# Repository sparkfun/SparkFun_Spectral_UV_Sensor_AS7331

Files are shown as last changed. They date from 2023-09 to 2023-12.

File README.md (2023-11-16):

SparkFun Spectral UV Sensor - AS7331 (Qwiic) 
========================================

<table class="table table-hover table-striped table-bordered">
    <tr align="center">
        <td><a href="https://www.sparkfun.com/products/23517">Standard</a></td>
        <td><a href="https://www.sparkfun.com/products/23518">Mini</a></td>
    </tr>
    <tr align="center">
        <td><a href="https://www.sparkfun.com/products/23517">SparkFun Spectral UV Sensor - AS7331 (Qwiic)</a></td>
        <td><a href="https://www.sparkfun.com/products/23518">SparkFun Mini Spectral UV Sensor - AS7331 (Qwiic)</a></td>
    </tr>
</table>

The SparkFun Spectral UV Sensor - AS7331 (Qwiic) features the AS7331 UV sensor from ams OSRAM<sup>&copy;</sup> and measures UV radiation on three channels: UVA (320-400nm), UVB (280-320nm), and UVC (200-280nm) with high sensitivity and accuracy. The three channels on the AS7331 each have individual photodiodes with built-in interference filters. The sensor has three operating modes: Single Measurement (CMD), Continuous Measurement (CONT), and Synchronized Measurement (SYNx) with an automatic power down sequence between measurements for low current consumption in all three modes. 

Repository Contents
-------------------

* **/Documentation** - Data sheets, additional product information
* **/Hardware** - Eagle design files (.brd, .sch)
* **/Production** - Production panel files (.brd)
* **/docs** -  Documentation files for the Spectral UV Sensor
* **/overrides** -  Overrides for GitHub pages content

Documentation
--------------
* **[Library](https://github.com/sparkfun/SparkFun_AS7331_Arduino_Library)** - Arduino library for the Spectral UV Sensor - AS7331 (Qwiic).
* **[Hookup Guide](https://sparkfun.github.io/SparkFun_Spectral_UV_Sensor_AS7331)** - Basic hookup guide for the Spectral UV Sensor - AS7331 (Qwiic).

Product Versions
----------------
* [SEN-23517](https://www.sparkfun.com/products/23517) - Spectral UV Sensor - AS7331 (Qwiic)
* [SEN-23518](https://www.sparkfun.com/products/23518) - Mini Spectral UV Sensor - AS7331 (Qwiic)

License Information
-------------------

This product is _**open source**_! 

Please review the LICENSE.md file for license information. 

If you have any questions or concerns on licensing, please contact technical support on our [SparkFun forums](https://forum.sparkfun.com/viewforum.php?f=152).

Distributed as-is; no warranty is given.

- Your friends at SparkFun.

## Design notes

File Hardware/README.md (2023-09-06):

SparkFun <PRODUCT NAME> Design Files
=====================================

The .sch and .brd files hare are Eagle CAD schematic and PCB design files from SparkFun Electronics.
A freeware version of Autodesk Eagle can be found [here](https://www.autodesk.com/products/eagle/free-download).

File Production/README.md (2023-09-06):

SparkFun <PRODUCT NAME> Production Files
=========================================

These are the production files SparkFun uses for printing PCBs.

License Information
-------------------
This product is open source! 

The hardware is released under [Creative Commons ShareAlike 4.0 International](https://creativecommons.org/licenses/by-sa/4.0/).

Please use, reuse, and modify these files as you see fit. Please maintain attribution to SparkFun Electronics and release anything derivative under the same license.

Distributed as-is; no warranty is given.

- Your friends at SparkFun.

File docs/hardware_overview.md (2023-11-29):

---
icon: material/cog
---

## AS7331 Spectral UV Sensor

The AS7331 spectral UV sensor from ams measures UV radiation over three channels (UVA, UVB, and UVC). Each channel is isolated from the other and has its own photodiode with a built-in filter to help with accuracy and interference from other channels.

<div class="grid" markdown>

<div markdown>
<figure markdown>
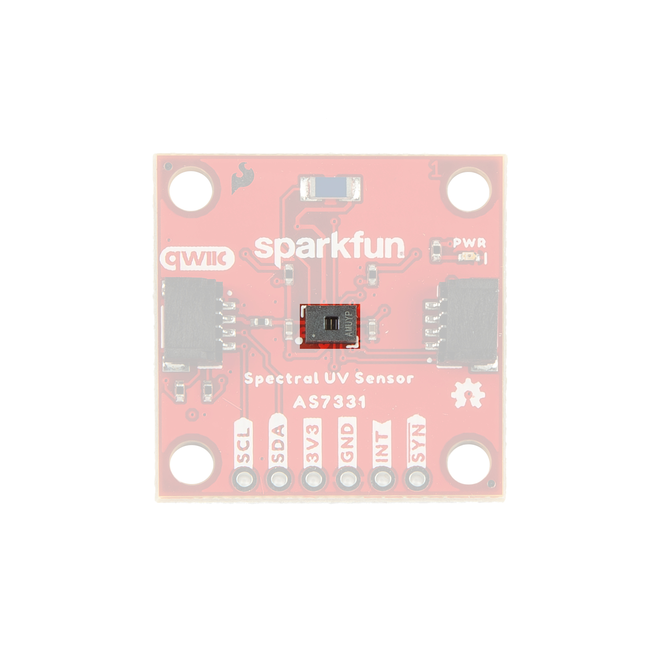
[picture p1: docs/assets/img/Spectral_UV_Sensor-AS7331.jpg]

</figure>
</div>

<div markdown>
<figure markdown>
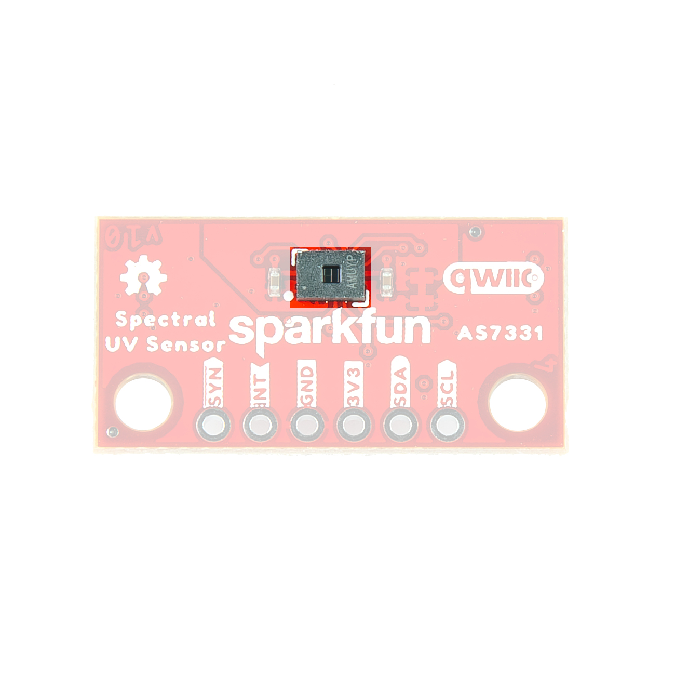
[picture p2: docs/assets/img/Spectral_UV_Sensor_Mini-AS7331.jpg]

</figure>
</div>

</div>

The AS7331 has extensive configuration options to customize the sensor's responsiveness, sensitivity, clock speed, and conversion time, among other settings. These configuration options allow users to optimize the sensor for their application. For example, a high gain setting results in a more sensitive response from the sensor but a lower maximum detectable irradiance (in &micro;W/cm<sup>2</sup>) whereas a low gain has much less sensitivity but a much higher maximum detectable irradiance. For detailed information on the conversion equations and how all the available settings affect performance, refer to section 7.4 of the [datasheet](./assets/component_documentation/AS7331_DS001047_4-00.pdf) Note, these configurations apply across all three channels. It has four operating modes: Command (CMD), Continuous (CONT), Synchronized Start (SYNS), and Synchronized Start/End (SYND). The list below outlines the operating modes' behaviors: 

* CMD Mode - "One-shot" mode. Takes a single measurement and conversion controlled by the I<sup>2</sup>C interface.
* CONT Mode - Continous mode. Takes continuous measurements and conversions on set intervals. 
* SYNS Mode - Synchronized start mode. A connected microcontroller starts measurements through an I/O pin connected to the SYN pin.
* SYND Mode - Synchronized start and stop mode. A connected microcontroller starts and stops measurements through an I/O pin connected to the SYN pin.

 The sensor operates over I<sup>2</sup>C with a pin-configured I<sup>2</sup>C address supporting four separate addresses (the breakout board sets this to 0x74 by default). Refer to the [datasheet](./assets/component_documentation/AS7331_DS001047_4-00.pdf) for a complete overview of the AS7331.

## Qwiic and PTH Pins

Both boards include a pair of Qwiic connectors for the I<sup>2</sup>C interface (SDA, SCL, 3.3V, and Ground) as well as a 0.1"-spaced plated through hole (PTH) header that includes power supply pins (3.3V and Ground) the I<sup>2</sup>C interface as well as the AS7331's SYNC and READY/INT pins.

<div class="grid" markdown>

<div markdown>
<figure markdown>
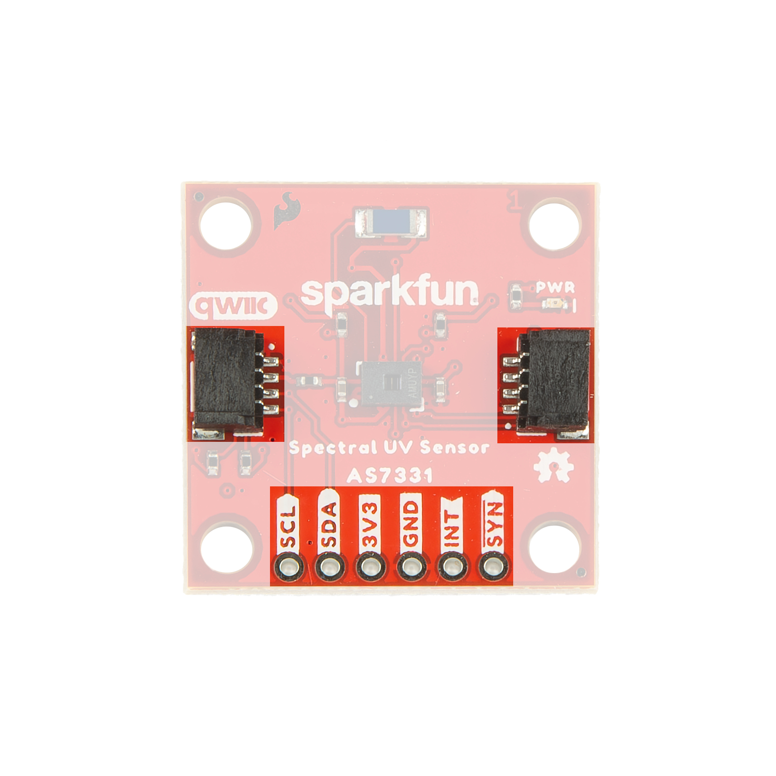
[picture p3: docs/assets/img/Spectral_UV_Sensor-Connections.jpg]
Highlighting the Qwiic connectors & PTH pins on the standard board

</figure>
</div>

<div markdown>
<figure markdown>
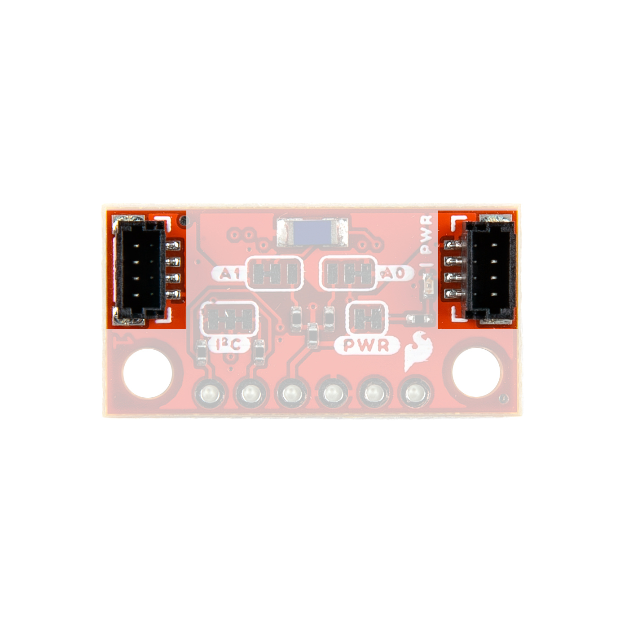
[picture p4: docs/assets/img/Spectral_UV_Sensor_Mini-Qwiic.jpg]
Highlighting the Qwiic connectors on the standard board

</figure>
</div>

</div>

### Power

The AS7331 accepts a supply voltage between <b>2.7V</b> and <b>3.6V</b>. Power to these boards can be supplied either over one of the Qwiic connectors or through the <b>3.3V</b> and <b>GND</b> PTH pins.

## LEDs

These breakouts only have a red Power LED to indicate whenever the board is powered.

<div class="grid" markdown>

<div markdown>
<figure markdown>
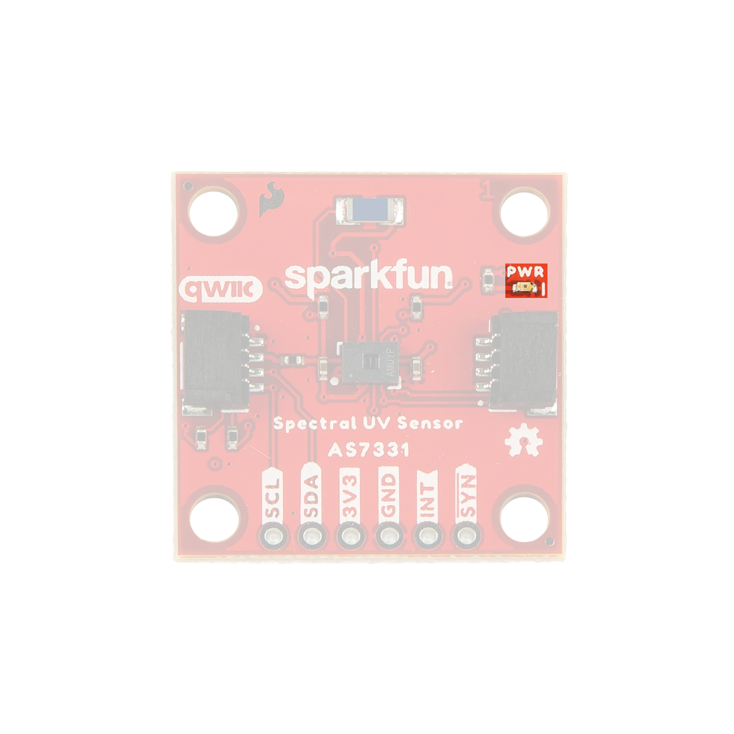
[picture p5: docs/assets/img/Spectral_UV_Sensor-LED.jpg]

</figure>
</div>

<div markdown>
<figure markdown>
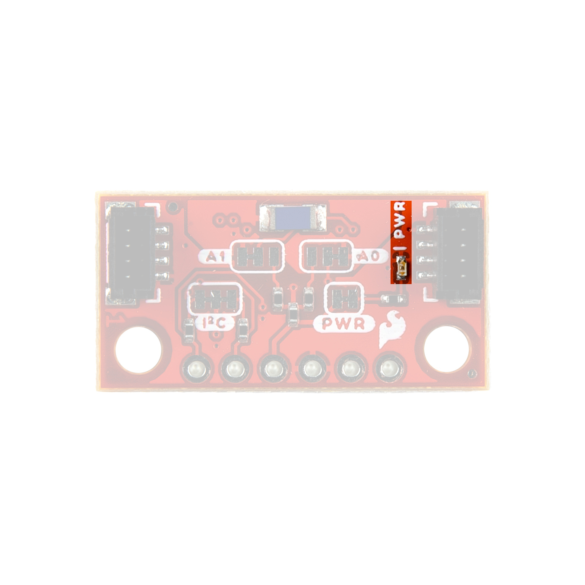
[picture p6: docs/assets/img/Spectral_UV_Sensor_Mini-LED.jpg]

</figure>
</div>

</div>

## Jumpers

??? note "Never modified a jumper before?"
	Check out our <a href="https://learn.sparkfun.com/tutorials/664">Jumper Pads and PCB Traces tutorial</a> for a quick introduction!
	<p align="center">
		<a href="https://learn.sparkfun.com/tutorials/664">
		Tutorial's thumbnail<br>
        How to Work with Jumper Pads and PCB Traces</a>
	</p>

The boards have three solder jumpers labeled <b>PWR</b>, <b>A0</b>, and <b>A1</b>. The PWR jumper completes the power LED circuit. Open it to disable the Power LED to help reduce the current consumption. The A0 and A1 solder jumpers control the AS7331's I<sup>2</sup>C address. They default to tie both address pins to Ground to set the I<sup>2</sup>C address to <b>0x74</b>. The table below outlines the jumper positions for the four available I<sup>2</sup>C addresses:

<div class="grid" markdown>

<div markdown>
<figure markdown>
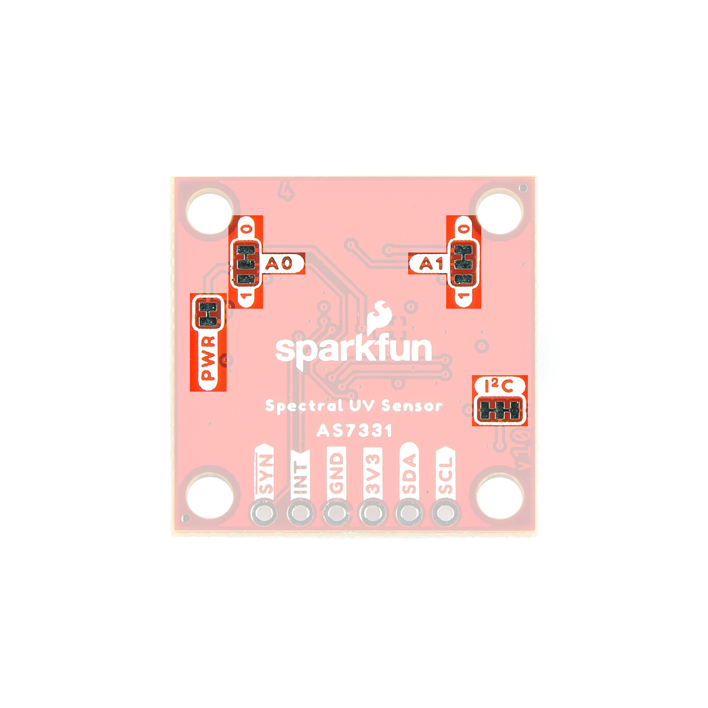
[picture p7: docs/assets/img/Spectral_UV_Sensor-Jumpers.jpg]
Highlighting the solder jumpers on the standard board

</figure>
</div>

<div markdown>
<figure markdown>
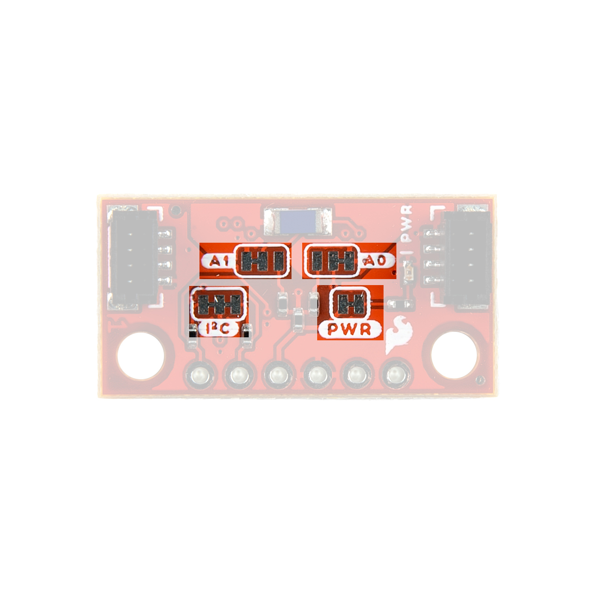
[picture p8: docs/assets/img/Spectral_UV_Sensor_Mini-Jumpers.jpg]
Highlighting the solder jumpers on the standard board

</figure>
</div>

</div>

<center>
<table>
	<tr>
		<th>A1</th>
		<th>A0</th>
		<th>Address</th>
	</tr>
	<tr>
		<td>GND</td>
		<td>GND</td>
		<td>0x74 (default)</td>
	</tr>
	<tr>
		<td>GND</td>
		<td>VDD</td>
		<td>0x75</td>
	</tr>
	<tr>
		<td>VDD</td>
		<td>GND</td>
		<td>0x76</td>
	</tr>
	<tr>
		<td>VDD</td>
		<td>VDD</td>
		<td>0x77</td>
	</tr>
</table>
</center>
## Board Dimensions

The Standard version of the Spectral UV Sensor measures 1.00" x 1.00" (25.4mm x 25.4mm) and the Mini version measures 1.00" x 0.50" (25.4mm x 12.7mm). The Standard has four mounting holes and the Mini has two mounting holes. All of these fit a [4-40 screw]().

<div class="grid" markdown>

<div markdown>
<figure markdown>
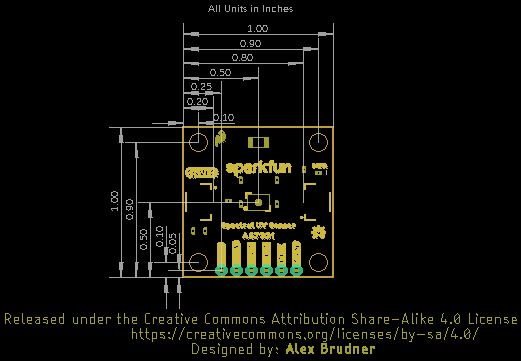
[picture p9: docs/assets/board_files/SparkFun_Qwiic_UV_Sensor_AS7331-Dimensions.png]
Spectral UV Sensor Standard Board Dimensions

</figure>
</div>

<div markdown>
<figure markdown>
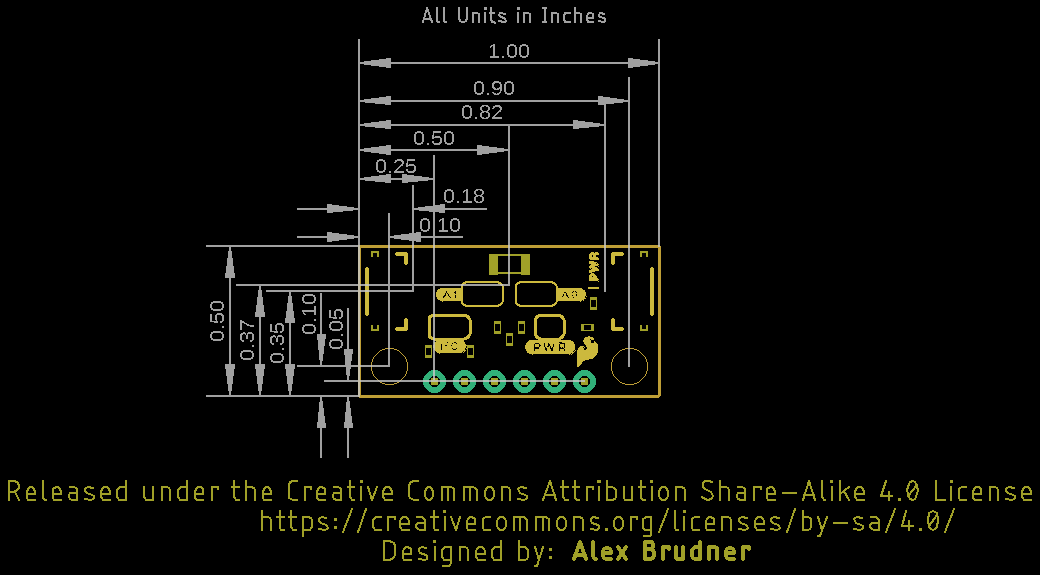
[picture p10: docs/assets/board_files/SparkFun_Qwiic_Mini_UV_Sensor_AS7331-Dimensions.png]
Spectral UV Sensor Mini Board Dimensions

</figure>
</div>

</div>

??? tip "Need more measurements?"
	For more information about the board's dimensions, users can download the Eagle files([Standard](./assets/board_files/SparkFun_Qwiic_UV_Sensor_AS7331.zip) & [Mini](./assets/board_files/SparkFun_Qwiic_Mini_UV_Sensor_AS7331.zip)) for the board. These files can be opened in Eagle and additional measurements can be made with the dimensions tool.

	??? info ":octicons-download-16:{ .heart } Eagle - Free Download!"
		Eagle is a [CAD]("computer-aided design") program for electronics that is free to use for hobbyists and students. However, it does require an account registration to utilize the software.

		<center>
		[Download from<br>:autodesk-primary:{ .autodesk }](https://www.autodesk.com/products/eagle/free-download "Go to downloads page"){ .md-button .md-button--primary width="250px" }
		</center>
	
	??? info ":straight_ruler: Dimensions Tool"
		This video from Autodesk demonstrates how to utilize the dimensions tool in Eagle, to include additional measurements:

		<center>
		<div class="video">
		<iframe src="https://www.youtube.com/embed/dZLNd1FtNB8" title="EAGLE Dimension Tool" frameborder="0" allow="accelerometer; autoplay; clipboard-write; encrypted-media; gyroscope; picture-in-picture" allowfullscreen></iframe>
		</div>
		</center>

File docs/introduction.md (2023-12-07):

---
icon: material/book-open-page-variant
---

The SparkFun Spectral UV Sensor - AS7331 (Qwiic) and Mini Spectral UV Sensor - AS7331 (Qwiic) feature the AS7331 UV sensor from ams OSRAM<sup>&copy;</sup> which measures UV radiation on three channels: UVA (320-400nm), UVB (280-320nm), and UVC (200-280nm). Each channel on the AS7331 has an individual photodiode with built-in interference filters to ensure high sensitivity and accuracy across all three channels. The AS7331 communicates over I<sup>2</sup>C so naturally we put it on Standard (1"x1") and Mini (1"x0.5") Qwiic breakouts to integrate into our [Qwiic Connect System](https://www.sparkfun.com/qwiic).

<section class="grid cards col-2"markdown>

-	<a href="https://www.sparkfun.com/products/23517">
	**SparkFun Spectral UV Sensor - AS7331 (Qwiic)**<br>
	**SKU:** SEN-23517

	---

	<figure markdown>
	https://cdn.sparkfun.com/r/600-600/assets/parts/2/3/8/0/8/23517-Spectral-UV-Sensor_Feature.jpg
	</figure>
	</a>

	<center>
    [Purchase from SparkFun :fontawesome-solid-cart-plus:{ .heart }](https://www.sparkfun.com/products/23517){ .md-button .md-button--primary }
    </center>

-	<a href="https://www.sparkfun.com/products/23518">
	**SparkFun Mini Spectral UV Sensor - AS7331 (Qwiic)**<br>
	**SKU:** SEN-23518

	---

	<figure markdown>
	https://cdn.sparkfun.com/r/600-600/assets/parts/2/3/8/0/9/23518-Spectral-UV-Sensor-Mini_Feature.jpg
	</figure></a>

	<center>
	[Purchase from SparkFun :fontawesome-solid-cart-plus:{ .heart }](https://www.sparkfun.com/products/23518){ .md-button .md-button--primary }
	</center>

</section>

This guide goes over the AS7331 UV sensor and other hardware on these Qwiic breakouts, how to assemble them into a circuit and how to use them with the SparkFun AS7331 Arduino library.

## Required Materials

In order to follow along with this guide, you'll need the following materials. You'll need a microcontroller to connect the breakouts to. The development boards listed below come with Qwiic connectors for easy connection using the Qwiic system:

<div class="grid cards" markdown>

-   <a href="https://www.sparkfun.com/products/19177">

    <figure markdown>
    SparkFun IoT RedBoard - ESP32 Development Board
    </figure>
    </a>
    ---
    <a href="https://www.sparkfun.com/products/19177">
    **SparkFun IoT RedBoard - ESP32 Development Board**<br>
    DEV-20168
    </a>

-   <a href="https://www.sparkfun.com/products/18158">
    
    <figure markdown>
    SparkFun RedBoard Plus
    </figure>
    </a>
    ---
    <a href="https://www.sparkfun.com/products/18158">
    **SparkFun RedBoard Plus**<br>
    DEV-18158
    </a>

-   <a href="https://www.sparkfun.com/products/15574">
    
    <figure markdown>
    SparkFun Thing Plus - Artemis
    </figure>
    </a>
    ---
    <a href="https://www.sparkfun.com/products/15574">
    **SparkFun Thing Plus - Artemis**<br>
    DEV-18158
    </a>

-   <a href="https://www.sparkfun.com/products/20168">

    <figure markdown>
    SparkFun Qwiic Pocket Development Board - ESP32-C6
    </figure>
    </a>
    ---
    <a href="https://www.sparkfun.com/products/22925">
    **SparkFun Qwiic Pocket Development Board - ESP32-C6**<br>
    DEV-22925
    </a>
</div>

If your chosen microcontroller is not already Qwiic-enabled, you can add that functionality with one or more of the following items:

<div class="grid cards" markdown>

-   <a href="https://www.sparkfun.com/products/15081">

    <figure markdown>
    SparkFun Qwiic Cable Kit
    </figure>
    </a>
    ---
    <a href="https://www.sparkfun.com/products/15081">
    **SparkFun Qwiic Cable Kit**<br>
    KIT-15081
    </a>

-   <a href="https://www.sparkfun.com/products/14495">
    
    <figure markdown>
    SparkFun Qwiic Adapter
    </figure>
    </a>
    ---
    <a href="https://www.sparkfun.com/products/14495">
    **SparkFun Qwiic Adapter**<br>
    DEV-14495
    </a>

-   <a href="https://www.sparkfun.com/products/14352">
    
    <figure markdown>
    SparkFun Qwiic Shield for Arduino
    </figure>
    </a>
    ---
    <a href="https://www.sparkfun.com/products/14352">
    **SparkFun Qwiic Shield for Arduino**<br>
    DEV-14352
    </a>

-   <a href="https://www.sparkfun.com/products/16790">

    <figure markdown>
    SparkFun Qwiic Shield for Thing Plus
    </figure>
    </a>
    ---
    <a href="https://www.sparkfun.com/products/16790">
    **SparkFun Qwiic Shield for Thing Plus**<br>
    DEV-16790
    </a>
</div>

You will also need at least one Qwiic cable to connect your breakout to your microcontroller:

<div class="grid cards" markdown>

-   <a href="https://www.sparkfun.com/products/17259">

    <figure markdown>
    Flexible Qwiic Cable - 100mm)
    </figure>
    </a>
    ---
    <a href="https://www.sparkfun.com/products/17259">
    **Flexible Qwiic Cable - 100mm**<br>
    PRT-17259
    </a>

-   <a href="https://www.sparkfun.com/products/17260">
    
    <figure markdown>
    Qwiic Cable - 50mm
    </figure>
    </a>
    ---
    <a href="https://www.sparkfun.com/products/17260">
    **Flexible Qwiic Cable - 50mm**<br>
    PRT-17260
    </a>

-   <a href="https://www.sparkfun.com/products/17257">
    
    <figure markdown>
    Flexible Qwiic Cable - 500mm
    </figure>
    </a>
    ---
    <a href="https://www.sparkfun.com/products/17257">
    **Flexible Qwiic Cable - 500mm**<br>
    PRT-17257
    </a>

-   <a href="https://www.sparkfun.com/products/17261">

    <figure markdown>
    Flexible Qwiic Cable - Female Jumper (4-pin)
    </figure>
    </a>
    ---
    <a href="https://www.sparkfun.com/products/17261">**Flexible Qwiic Cable - Female Jumper (4-pin)**<br>
    CAB-17261
    </a>
</div>

## Optional Materials

If you prefer a soldered connection or want to modify the solder jumpers on these Qwiic breakouts you you may need some of the products listed below:

<div class="grid cards" markdown align="center">

-   <a href="https://www.sparkfun.com/products/116">

    <figure markdown>
    Break Away Headers - Straight)
    </figure>
    </a>
    ---
    <a href="https://www.sparkfun.com/products/116">
    **Break Away Headers - Straight**<br>
    PRT-00116
    </a>

-   <a href="https://www.sparkfun.com/products/14681">
    
    <figure markdown>
    SparkFun Beginner Tool Kit
    </figure>
    </a>
    ---
    <a href="https://www.sparkfun.com/products/14681">
    **SparkFun Beginner Tool Kit**<br>
    TOL-14681
    </a>

-   <a href="https://www.sparkfun.com/products/9200">
    
    <figure markdown>
    Hobby Knife
    </figure>
    </a>
    ---
    <a href="https://www.sparkfun.com/products/9200">
    **Hobby Knife**<br>
    TOL-09200
    </a>

-   <a href="https://www.sparkfun.com/products/14579">

    <figure markdown>
    Chip Quik No-Clean Flux Pen - 10mL
    </figure>
    </a>
    ---
    <a href="https://www.sparkfun.com/products/14579">**Chip Quik No-Clean Flux Pen - 10mL**<br>
    CAB-14579
    </a>
</div>

## Suggested Reading

We designed this board for integration into SparkFun's Qwiic connect system.  Click on the banner below to learn more about the [SparkFun Qwiic Connect System](https://www.sparkfun.com/qwiic).

<div style="text-align: center">
<table>
  <tr>
   <td>
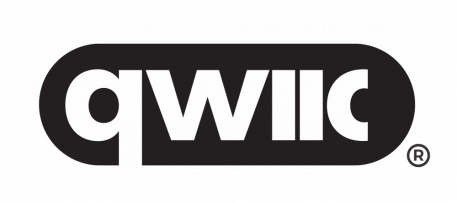
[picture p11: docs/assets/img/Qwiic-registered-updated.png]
Qwiic Connect System Click to learn more about the Qwiic Connect System!
   <div style="text-align: center"></div>
   </td>
  </tr>
  <tr>
    <td><div style="text-align: center"><i><a href="https://www.sparkfun.com/qwiic">Qwiic Connect System</a></i></div></td>
  </tr>
</table>
</div>

Before getting started with this Hookup Guide, you may want to read through the tutorials below if you are not familiar with the concepts covered in them or want a refresher. If you are using either of the Qwiic Shields linked above, we recommend reading through their respective Hookup Guides before continuing with this tutorial:

<div class="grid cards hide col-4" markdown align="center">

-   <a href="https://learn.sparkfun.com/tutorials/8">
    <figure markdown>
    Serial Communication
    </figure>
    </a>
    <a href="https://learn.sparkfun.com/tutorials/8">**Serial Communication**
    </a>

-   <a href="https://learn.sparkfun.com/tutorials/82">
    <figure markdown>
    I2C
    </figure>
    </a>
    <a href="https://learn.sparkfun.com/tutorials/82">**I2C**
    </a>

-   <a href="https://learn.sparkfun.com/tutorials/62">
    <figure markdown>
    Logic Levels
    </figure>
    </a>
    <a href="https://learn.sparkfun.com/tutorials/62">**Logic Levels**
    </a>

-   <a href="https://learn.sparkfun.com/tutorials/61">
    <figure markdown>
    Installing Arduino IDE
    </figure>
    </a>
    <a href="https://learn.sparkfun.com/tutorials/61">**Installing Arduino IDE**
    </a>

-   <a href="https://learn.sparkfun.com/tutorials/15">
    <figure markdown>
    Installing an Arduino Library
    </figure>
    </a>
    <a href="https://learn.sparkfun.com/tutorials/15">**Installing an Arduino Library**
    </a>

-   <a href="https://learn.sparkfun.com/tutorials/112">
    <figure markdown>
    Serial Terminal Basics
    </figure>
    </a>
    <a href="https://learn.sparkfun.com/tutorials/112">**Serial Terminal Basics**
    </a>

-   <a href="https://learn.sparkfun.com/tutorials/664">
    <figure markdown>
    How to Work with Jumper Pads and PCB Traces
    </figure>
    </a>
    <a href="https://learn.sparkfun.com/tutorials/664">**How to Work with Jumper Pads and PCB Traces**
    </a>

-   <a href="https://learn.sparkfun.com/tutorials/684">
    <figure markdown>
    Qwiic Shield for Arduino & Photon Hookup Guide
    </figure>
    </a>
    <a href="https://learn.sparkfun.com/tutorials/684">**Qwiic Shield for Arduino & Photon Hookup Guide**
    </a>

-   <a href="https://learn.sparkfun.com/tutorials/1107">
    <figure markdown>
    Qwiic Shield for Thing Plus Hookup Guide
    </figure>
    </a>
    <a href="https://learn.sparkfun.com/tutorials/1107">**Qwiic Shield for Thing Plus Hookup Guide**
    </a>
</div>

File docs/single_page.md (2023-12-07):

---
hide:
  - navigation
  - toc
icon: fontawesome/solid/scroll
---

# Introduction
--8<-- "./docs/introduction.md:5"

# Hardware Overview
--8<-- "./docs/hardware_overview.md:5"

# Hardware Assembly
--8<-- "./docs/hardware_assembly.md:5"

# <Product Name> Arduino Library

## Software Setup
--8<-- "./docs/software_setup.md:5"

## Arduino Examples
--8<-- "./docs/examples.md"

# Troubleshooting Tips
--8<-- "./docs/troubleshooting_tips.md:5"

# Resources:
--8<-- "./docs/resources.md"

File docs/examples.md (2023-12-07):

---
icon: simple/arduino
---

Now that we have the AS7331 Arduino library installed, let's take a closer look at a couple of the examples included in it.

## Example 1 - Basic One-Shot

The first example demonstrates the basics of configuring the AS7331, initializing it on the I<sup>2</sup>C bus to operate in command (one-shot) mode and printing out measured data over serial. This helps conserve power as the sensor powers on for a single measurement and conversion and then powers back down to sleep mode. Open the example in Arduino by navigating to <b>File</b> > <b>Examples</b> > <b>SparkFun AS7331 Arduino Library</b> > <b>Example01_Basic_OneShot</b> or you can copy the code below into a blank sketch. Select your <b>Board</b> and <b>Port</b> and click the <b>"Upload"</b> button.

??? "Example 1 - Basic One Shot"

    ```
     --8<-- "https://raw.githubusercontent.com/sparkfun/SparkFun_AS7331_Arduino_Library/main/examples/Example01_Basic_OneShot/Example01_Basic_OneShot.ino"
    ```

Once the code finishes uploading, open the [serial monitor](https://learn.sparkfun.com/tutorials/terminal-basics/arduino-serial-monitor-windows-mac-linux) with the baud set to <b>115200</b> and you should see the initialization success messages and then UV data begin to print out every 2 seconds like the screenshot below shows:

<div markdown>
<figure markdown>
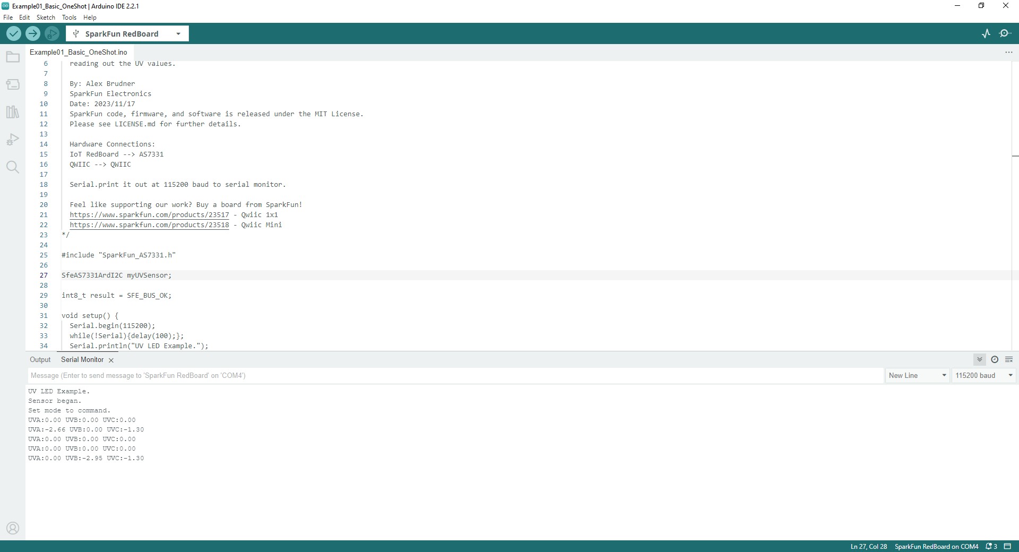
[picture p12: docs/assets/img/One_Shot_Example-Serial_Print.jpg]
One Shot example serial print

<figcaption><i>Having trouble seeing the detail in the image? Click on it for a larger view.</i></figcaption>
</figure>
</div>

### Code to Note

The <code>myUVSensor.begin</code> function sets the AS7331 to operate in Command Mode (One Shot) by default. Switching to other modes requires calling the <code>myUVSensor.startMeasurement(MEAS_MODE_CONT)</code>. The other examples in the library demonstrate how to switch to the other three operating modes.

## Example 2 - Continuous Mode

Example 2 demonstrates how to change from the default settings to have the AS7331 operate in Continuous Mode. This example requires some additional assembly to connect the INT pin to an [interrupt-capable pin](https://www.arduino.cc/reference/en/language/functions/external-interrupts/attachinterrupt/) on your microcontroller. The example defaults to use D26 so adjust this line if you change which pin is used for the interrupt:

``` c++
const uint8_t interruptPin = 26;
``` 

Open the example in Arduino by navigating to <b>File</b> > <b>Examples</b> > <b>SparkFun AS7331 Arduino Library</b> > <b>Example01_Basic_OneShot</b> or you can copy the code below into a blank sketch. Select your <b>Board</b> and <b>Port</b> and click the <b>"Upload"</b> button.

??? "Example 2 - CONT Mode"

    ```
     --8<-- "https://raw.githubusercontent.com/sparkfun/SparkFun_AS7331_Arduino_Library/main/examples/Example02_CONT_Mode/Example02_CONT_Mode.ino"
    ```

After uploading, open the serial monitor with the baud set to <b>115200</b> and you should see the initialization messages print out followed by a continuous flow of UV data.

### Code to Note

As mentioned above, the <code>myUVSensor.begin</code> function sets the AS7331 to operate in Command Mode so after initializing the sensor the code sets the AS7331 to operate in Continuous Mode:

``` c++
// Set measurement mode and change device operating mode to measure.
  if(myUVSensor.startMeasurement(MEAS_MODE_CONT) == false) {
    Serial.println("Sensor did not get set properly.");
    Serial.println("Spinning...");
    while(1);
```

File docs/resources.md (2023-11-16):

For more information about the Spectral UV Sensor - Qwiic, check out the following resources listed below: 

* Schematic:
    * [Standard](./assets/board_files/SparkFun_Qwiic_UV_Sensor_AS7331.pdf)
    * [Mini](./assets/board_files/SparkFun_Qwiic_Mini_UV_Sensor_AS7331-Dimensions.png)
* Eagle Files:
    * [Standard](./assets/board_files/SparkFun_Qwiic_UV_Sensor_AS7331.zip)
    * [Mini](./assets/board_files/SparkFun_Qwiic_Mini_UV_Sensor_AS7331.zip)
* Board Dimensions:
    * [Standard](./assets/board_files/SparkFun_Qwiic_UV_Sensor_AS7331-Dimensions.png)
    * [Mini](./assets/board_files/SparkFun_Qwiic_Mini_UV_Sensor_AS7331-Dimensions.png)
* [Datasheet](./assets/component_documentation/AS7331_DS001047_4-00.pdf) (AS7311)
* [SparkFun AS7331 Arduino Library](https://github.com/sparkfun/SparkFun_AS7331_Arduino_Library)
* [Hardware GitHub Respository](https://github.com/sparkfun/SparkFun_Spectral_UV_Sensor_AS7331)

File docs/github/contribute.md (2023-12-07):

# Contribute: Make an Augmentation!
Spot an improvement opportunity? Feel free to contribute to our open-source design and documentation. 

## :material-file-document-multiple:&nbsp;Improve our Documentation
All of this documentation can be modified by you! Please help us make it better.

* These pages are contained in the [`docs` folder](https://github.com/sparkfun/SparkFun_Spectral_UV_Sensor_AS7331/tree/main/docs) of the [SparkFun Spectral UV Sensor - AS7331 repository](https://github.com/sparkfun/SparkFun_Spectral_UV_Sensor_AS7331).

<!-- ### :material-source-pull:&nbsp;Submit a Correction -->
### Submit a Correction

1. With a GitHub account, [fork this repository](https://github.com/sparkfun/SparkFun_Spectral_UV_Sensor_AS7331/fork).
2. Add your corrections or improvements to the markdown file.
3. File a pull request with your changes, and enjoy making the ~~words~~ ~~worlds~~ world a better place.
	* Once received, the documentation specialist will automatically be notified.
	* We will review your suggested improvements to make sure they are correct and fit within our documentation standards.

## :material-cog:&nbsp;Improve our Hardware Design
All of our designs are open-source! Please help us make it better.

* Our board design files are contained in the [`Hardware` folder](https://github.com/sparkfun/SparkFun_Spectral_UV_Sensor_AS7331/tree/main/Hardware) of the [SparkFun Spectral UV Sensor - AS7331 repository](https://github.com/sparkfun/SparkFun_Spectral_UV_Sensor_AS7331).

<!-- ### :material-source-pull:&nbsp;Submit a Design Enhancement -->
### Submit a Design Enhancement

1. With a GitHub account, [fork this repository](https://github.com/sparkfun/SparkFun_Spectral_UV_Sensor_AS7331/fork).
2. Add your design augmentation(s)
3. File a pull request with your changes, and enjoy making the ~~words~~ ~~worlds~~ world a better place.
	1. Once received, the engineer in charge of the original design will automatically be notified.
	2. We will review your suggested improvement(s) to verify that they are within our board design standards and meet our product design requirements.
	3. If approved, we will flag these changes for our next board revision. Congrats! 🍻

		!!! info
			Even if your suggestion is accepted, these changes may not be immediately available for purchase. We may have to cycle through our current product inventory first.

## Contributors&nbsp;:clap:
Let's provide some recognition to the contributors for this project!

GitHub Contributors Image
<br>


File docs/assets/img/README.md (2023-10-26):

img directory
====================
This folder should contain the images for the product documentation

## General Images
* `sfe_logo_sm.png` - SparkFun flame logo (Cover page for with-pdf extension)
* `sfe_logo_sq.png` - SparkFun flame logo (favicon)

## Directory
* `qr_code` - QR codes for the product documentation

### QR Codes
* [QR code generator](https://qrgenerator.org/)
    * Flame Color: #E0311D
    * Frame Color: #3C464D
* [Remove meta data from svg](https://jakearchibald.github.io/svgomg/)

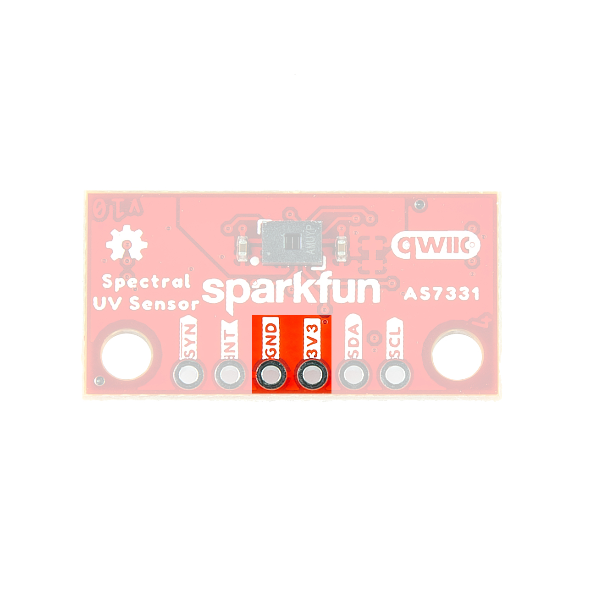
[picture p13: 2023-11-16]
site/assets/img/Spectral_UV_Sensor_Mini-Power_PTHs.jpg

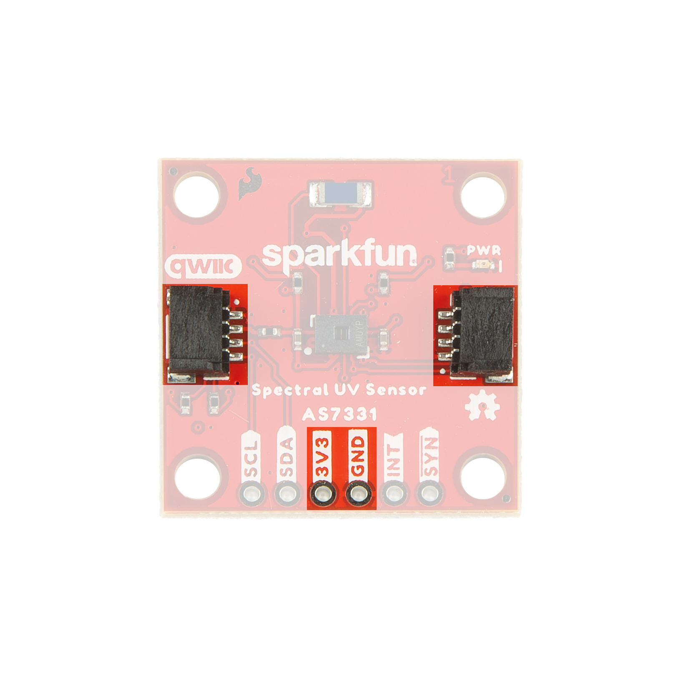
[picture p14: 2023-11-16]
site/assets/img/Spectral_UV_Sensor-Power.jpg

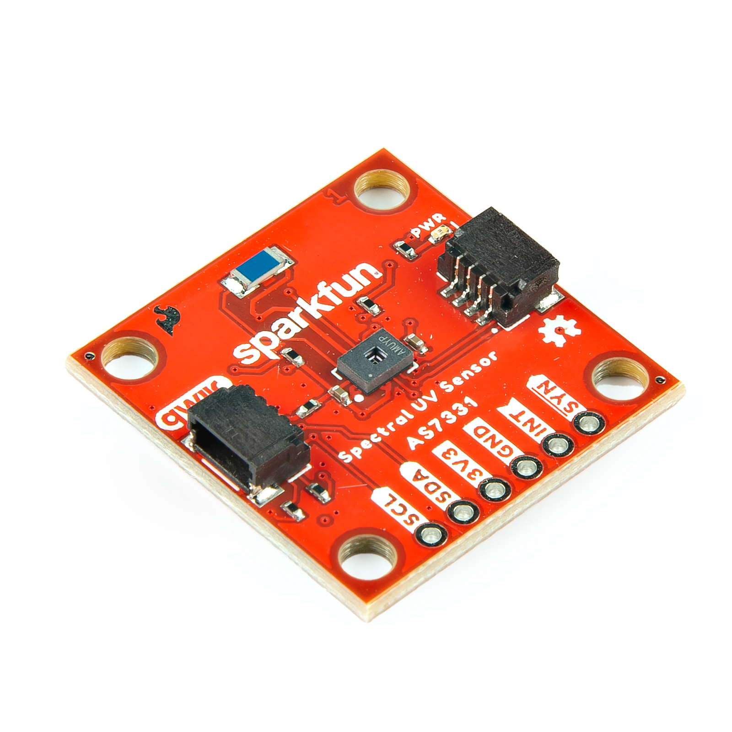
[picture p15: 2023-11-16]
site/assets/img/Spectral_UV_Sensor-Thumb.jpg

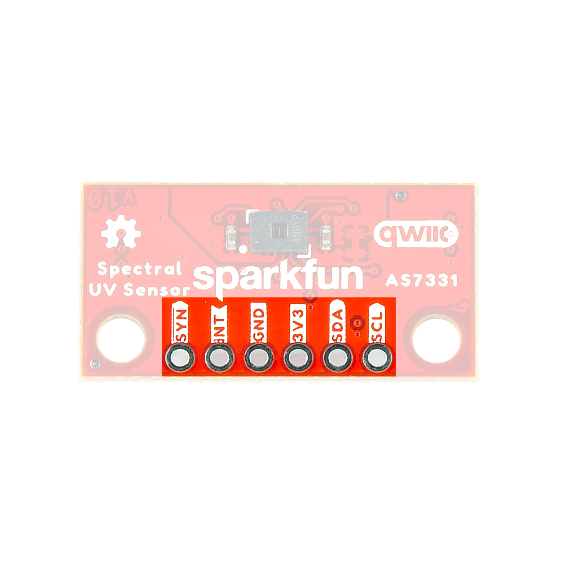
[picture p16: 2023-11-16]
site/assets/img/Spectral_UV_Sensor_Mini-PTHs.jpg

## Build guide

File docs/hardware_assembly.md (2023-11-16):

---
icon: material/tools
---

## Qwiic Assembly

Assembling these breakouts into a Qwiic circuit is as simple as plugging the board into your chosen microcontroller with a Qwiic cable. After assembling your circuit, it should look similar to the photos below:

<div class="grid" markdown>

<div markdown>
<figure markdown>
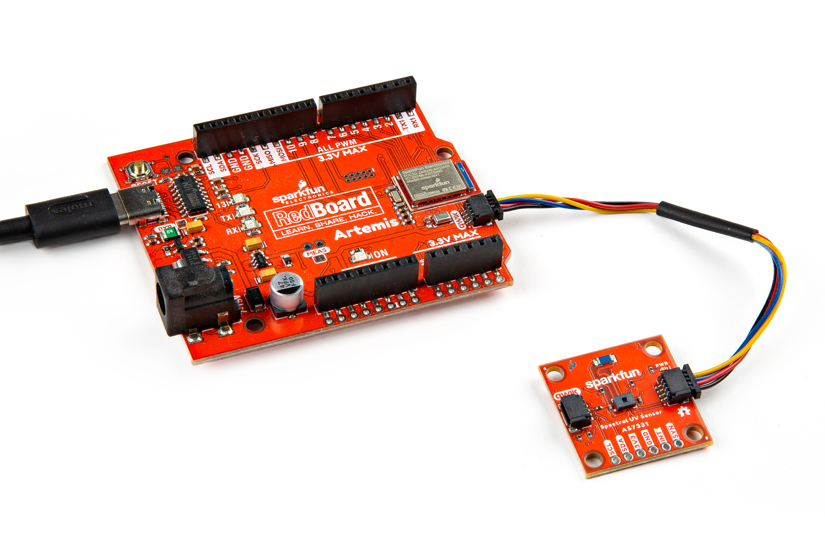
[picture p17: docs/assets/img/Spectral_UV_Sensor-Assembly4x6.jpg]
Standard board Qwiic assembly

</figure>
</div>

<div markdown>
<figure markdown>
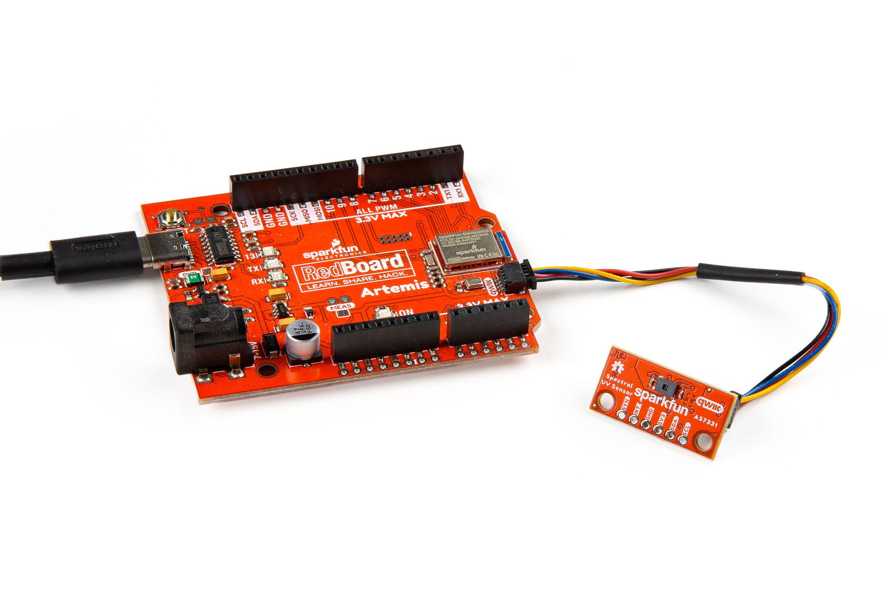
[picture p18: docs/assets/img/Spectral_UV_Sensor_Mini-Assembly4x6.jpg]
Mini board Qwiic assembly

</figure>
</div>

</div>

## Soldered Assembly

Users who prefer a soldered connection or wish to use the SYNC and READY/INT pins should solder to the board for permanent connections.

??? note "New to soldering?"
	If you have never soldered before or need a quick refresher, check out our [How to Solder: Through-Hole Soldering](https://learn.sparkfun.com/tutorials/how-to-solder-through-hole-soldering) guide.
	<p align="center">
		<a href="https://learn.sparkfun.com/tutorials/5">
		Tutorial's thumbnail<br>
        How to Solder: Through-Hole Soldering</a>
	</p>

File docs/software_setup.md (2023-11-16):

---
icon: simple/arduino
---

## Arduino IDE

Most users may already be familiar with the Arduino IDE and its use. However, for those of you who have never heard the name *Arduino* before, feel free to check out the [Arduino website](https://www.arduino.cc/en/Guide/HomePage). To get started with using the Arduino IDE, check out our tutorials below:

<div class="grid cards" markdown align="center">

<!-- -   <a href="https://learn.sparkfun.com/tutorials/50">
	<figure markdown>
	![What is an Arduino?](https://cdn.sparkfun.com/c/264-148/assets/3/b/6/e/b/512e66bece395f492b000000.jpg)</figure>

    ---
    **What is an Arduino?**
	</a> -->

-   <a href="https://learn.sparkfun.com/tutorials/61">
	<figure markdown>
	Installing the Arduino IDE
	</figure>

    ---
        
    **Installing the Arduino IDE**</a>

-   <a href="https://learn.sparkfun.com/tutorials/15">
    Installing an Arduino Library
	</figure>
    
    ---
    
    **Installing an Arduino Library**</a>

-   <a href="https://learn.sparkfun.com/tutorials/1265">
    <figure markdown>
	Installing Board Definitions in the Arduino IDE
	</figure>
    
    ---
    
    **Installing Board Definitions in the Arduino IDE**</a>

</div>

## SparkFun AS7331 Arduino Library

We've written an Arduino library for users to quickly get started with and customize the Spectral UV Sensor Breakouts. Install the library through the Arduino Library Manager tool by searching for "SparkFun AS7331". If you prefer to manually install the library, download a .ZIP of it from the [GitHub Repository](https://github.com/sparkfun/SparkFun_AS7331_Arduino_Library) by clicking the button below:

<center>
[SparkFun AS7331 Arduino Library (ZIP)](https://github.com/sparkfun/SparkFun_AS7331_Arduino_Library/archive/refs/heads/main.zip){ .md-button .md-button--primary }
</center>

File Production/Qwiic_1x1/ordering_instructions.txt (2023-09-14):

panel size, 169x117mm
PCB thickness, 1.6mm
number of layers, 4
controlled impedance, JLC7628
soldermask color, Red
silkscreen color, White
oz copper, 1oz
finish, HASL lead free
stencils, top+bottom
pcs per panel, 24
min trace width, 0.2032mm / 0.0080in
min drill size, 0.3048mm / 0.0120in
filename to layer stackup 1/2/3/4: GTL, GL2, GL3, GBL

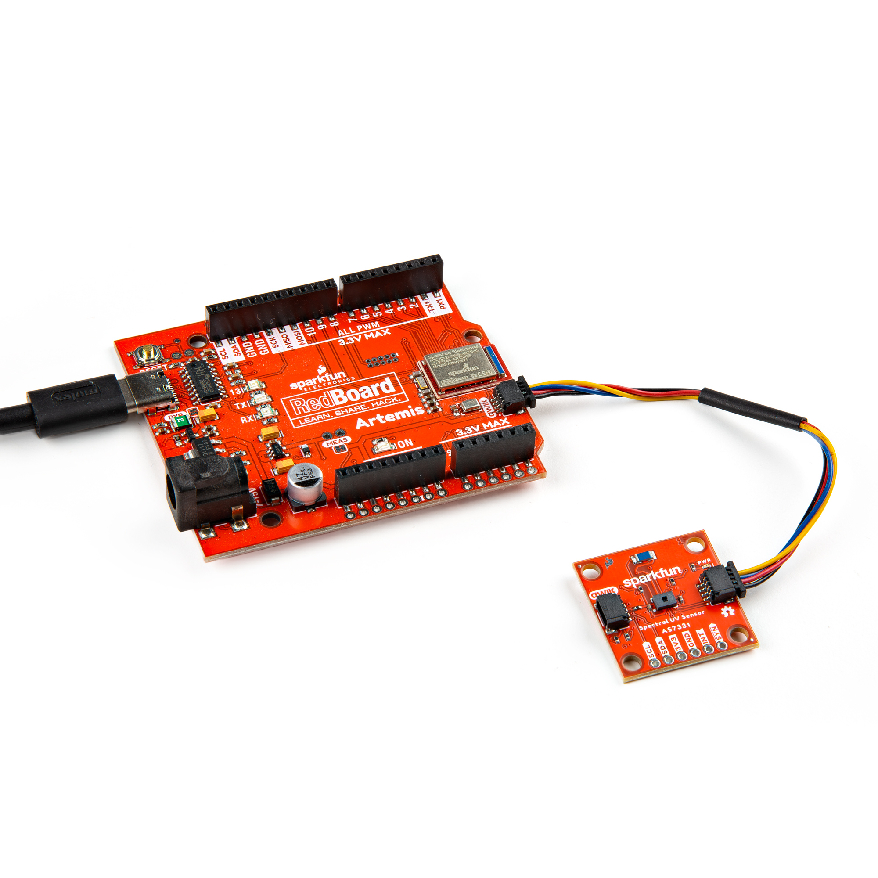
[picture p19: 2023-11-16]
site/assets/img/Spectral_UV_Sensor-AssemblySQ.jpg

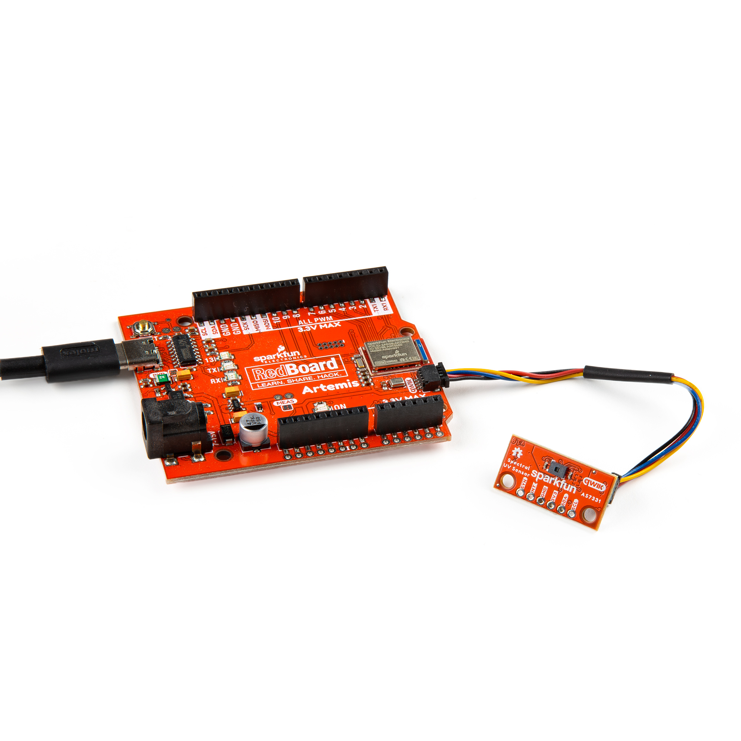
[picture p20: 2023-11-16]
site/assets/img/Spectral_UV_Sensor_Mini-AssemblySQ.jpg

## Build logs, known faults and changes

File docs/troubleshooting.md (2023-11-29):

## General Troubleshooting

!!! info
    <p><span class="glyphicon glyphicon-question-sign" aria-hidden="true"></span> <strong>Not working as expected and need help? </strong></p>
    <p>If you need technical assistance and more information on a product that is not working as you expected, we recommend heading on over to the <a href="https://www.sparkfun.com/technical_assistance">SparkFun Technical Assistance</a> page for some initial troubleshooting.</p>
    <center>
    [SparkFun Technical Assistance Page](https://www.sparkfun.com/technical_assistance){ .md-button .md-button--primary }
    </center>
    <p>If you can't find what you need there, you'll need a <a href="https://forum.sparkfun.com/ucp.php?mode=register">Forum Account</a> to search product forums and post questions.<p>

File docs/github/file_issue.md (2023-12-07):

# Did we make a mistake?

Spot something wrong? Please let us know. 

<!-- Technical Assistance Box -->
!!! warning "Need Help?"
    If you need technical assistance or more information on a product that is not working as you expected, we recommend heading on over to the [SparkFun Technical Assistance](https://www.sparkfun.com/technical_assistanc) page for some initial troubleshooting. This **Submit Issues** page is not where users should seek assistance.

    <center>
    [SparkFun Technical Assistance Page](https://www.sparkfun.com/technical_assistance){ .md-button .md-button--primary }
    </center>
    
    If you can't find what you need there, the [SparkFun Forums](https://forum.sparkfun.com/index.php) is a great place to search the product forums and ask questions.
    
    !!! info "Account Registration Required"
        For your first visit to our forum, you'll need to create a [Forum Account](https://forum.sparkfun.com/ucp.php?mode=register) to post questions.

## Discrepancies in the Documentation

All of our documentation can be modified by you! Please help us make it better.

* The documentation files for these pages are contained in the [`docs` folder](https://github.com/sparkfun/SparkFun_Spectral_UV_Sensor_AS7331/tree/main/docs) of the [SparkFun Spectral UV Sensor - AS7331 repository](https://github.com/sparkfun/SparkFun_Spectral_UV_Sensor_AS7331).

### 🔍 Spot something wrong?

If a section of the documentation is incorrect, please [open an issue](https://github.com/sparkfun/SparkFun_Spectral_UV_Sensor_AS7331/issues) and let us know.

### Do you have a suggested correction?

1. With a GitHub account, [fork this repository](https://github.com/sparkfun/SparkFun_Spectral_UV_Sensor_AS7331/fork).
2. Add your correction(s) or improvement(s) to the markdown file(s)
3. File a pull request with your changes, and enjoy making the ~~words~~ ~~worlds~~ world a better place.
	* Once received, the documentation specialist will automatically be notified.
	* We will review your suggested improvement(s) to make sure they are correct and fit within our documentation standards.

## Problems in the Hardware Design

All of our designs are open-source! Please help us make it better.

* Our board design files are contained in the [`Hardware` folder](https://github.com/sparkfun/SparkFun_Spectral_UV_Sensor_AS7331/tree/main/Hardware) of the [SparkFun Spectral UV Sensor - AS7331 repository](https://github.com/sparkfun/SparkFun_Spectral_UV_Sensor_AS7331).

### Does something not make sense? 🤔

If part of the design is confusing, please [open an issue](https://github.com/sparkfun/SparkFun_Spectral_UV_Sensor_AS7331/issues) and let us know.

### Did we forget to include an important function of the board? 🤦

If part of the board's functionality is missing, please [open an issue](https://github.com/sparkfun/SparkFun_Spectral_UV_Sensor_AS7331/issues) and file a feature request.

!!! tip "Design Considerations"
	Please keep in mind that we may intentionally exclude certain functions of the board to meet our product design requirements.
	
	* *For example, our Qwiic Micro boards are intended to fit on a small board layout and only use I<sup>2</sup>C communication; therefore, we may not have the SPI and interrupt pins available for users.*

### Do you wish to contribute directly to improving the board design?

1. With a GitHub account, [fork this repository](https://github.com/sparkfun/SparkFun_Spectral_UV_Sensor_AS7331/fork).
2. Add your design augmentation(s)
3. File a pull request with your changes, and enjoy making the ~~words~~ ~~worlds~~ world a better place.
	1. Once received, the engineer in charge of the original design will automatically be notified.
	2. We will review your suggested improvement(s) to verify that they are within our board design standards and meet our product design requirements.
	3. If approved, we will flag these changes for our next board revision. Congrats! 🍻

		!!! info
			Even if your suggestion is accepted, these changes may not be immediately available for purchase. We may have to cycle through our current product inventory first.

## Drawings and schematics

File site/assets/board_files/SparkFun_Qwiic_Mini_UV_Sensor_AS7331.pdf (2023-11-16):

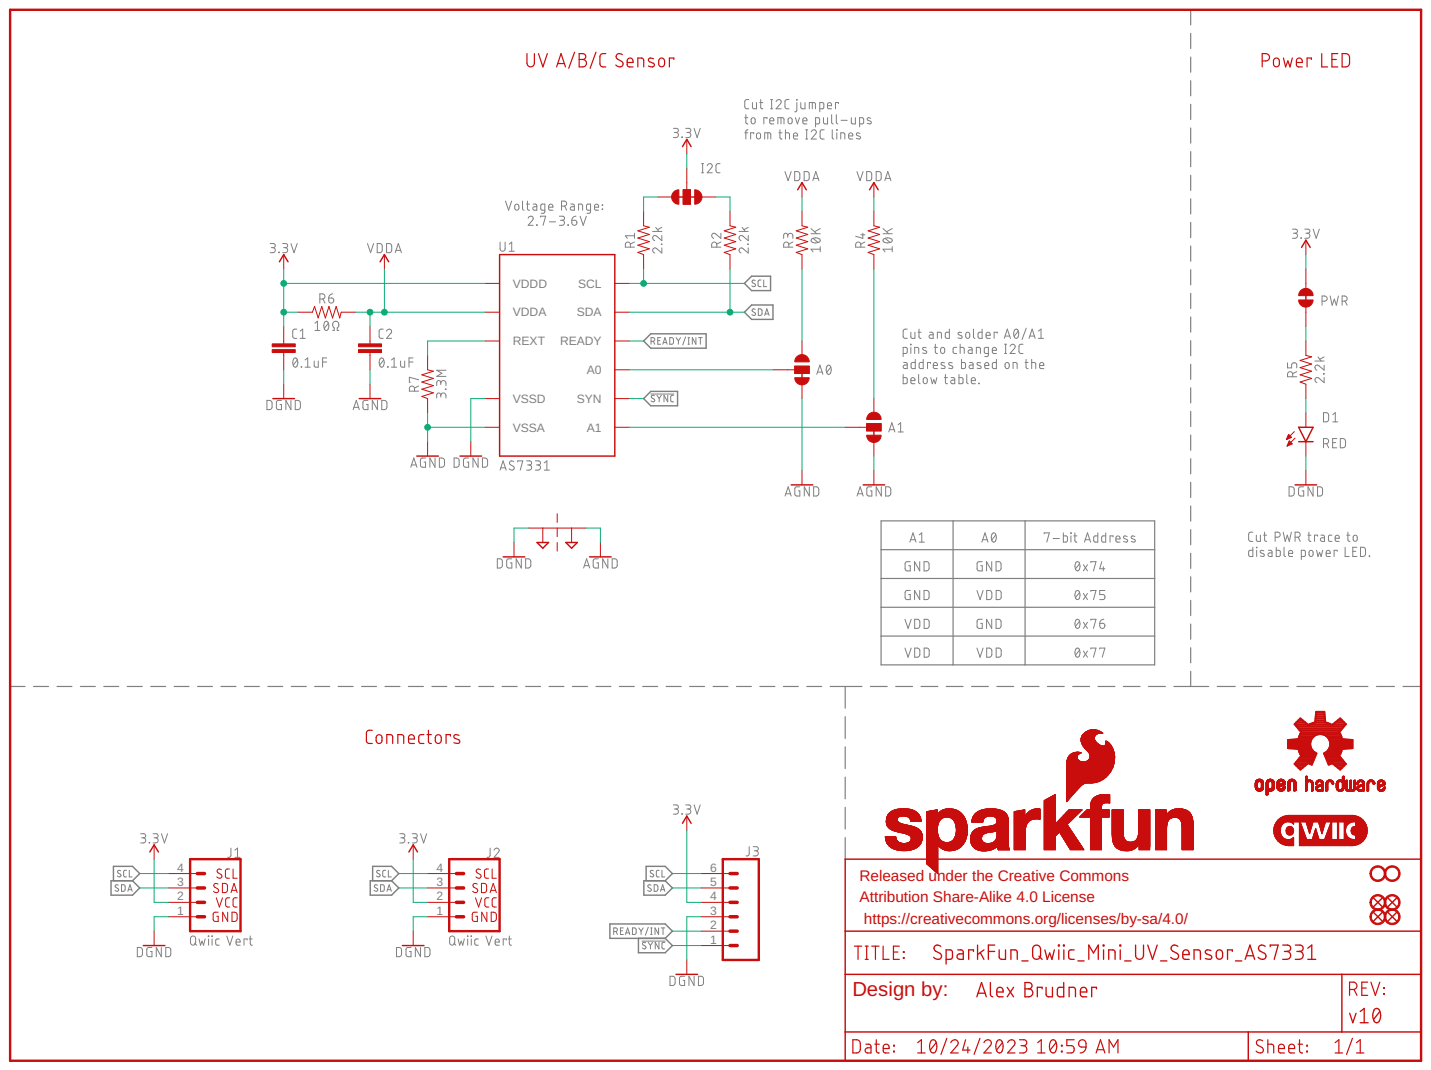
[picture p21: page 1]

https://creativecommons.org/licenses/by-sa/4.0/

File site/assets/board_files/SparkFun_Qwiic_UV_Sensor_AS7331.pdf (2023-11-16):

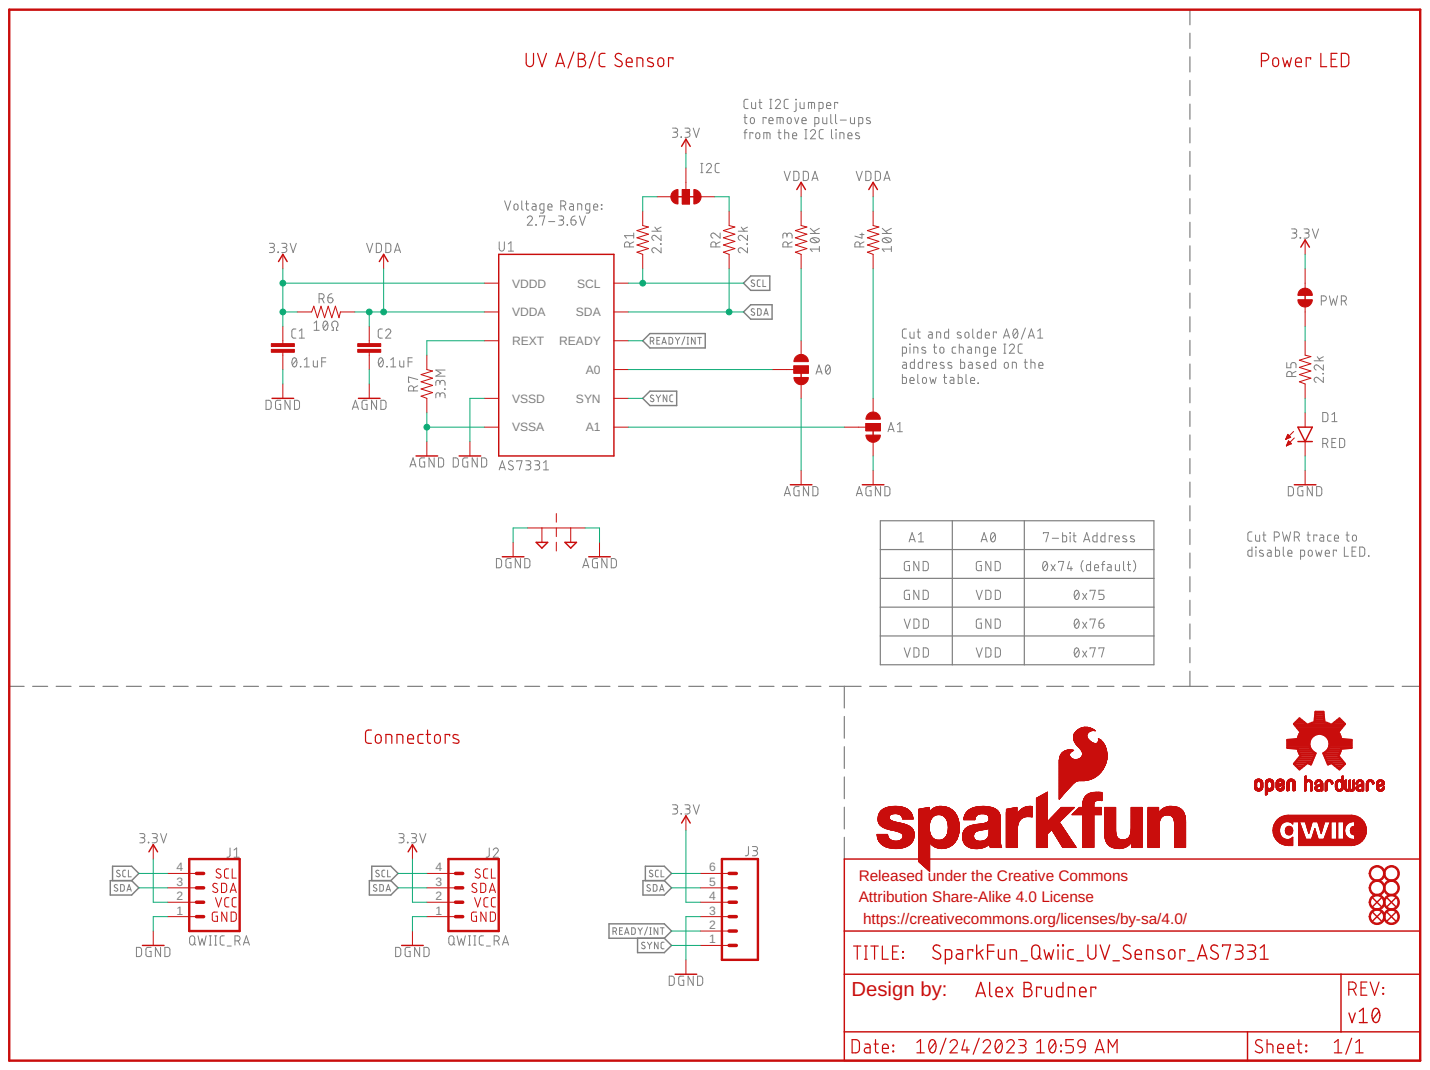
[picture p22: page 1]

https://creativecommons.org/licenses/by-sa/4.0/

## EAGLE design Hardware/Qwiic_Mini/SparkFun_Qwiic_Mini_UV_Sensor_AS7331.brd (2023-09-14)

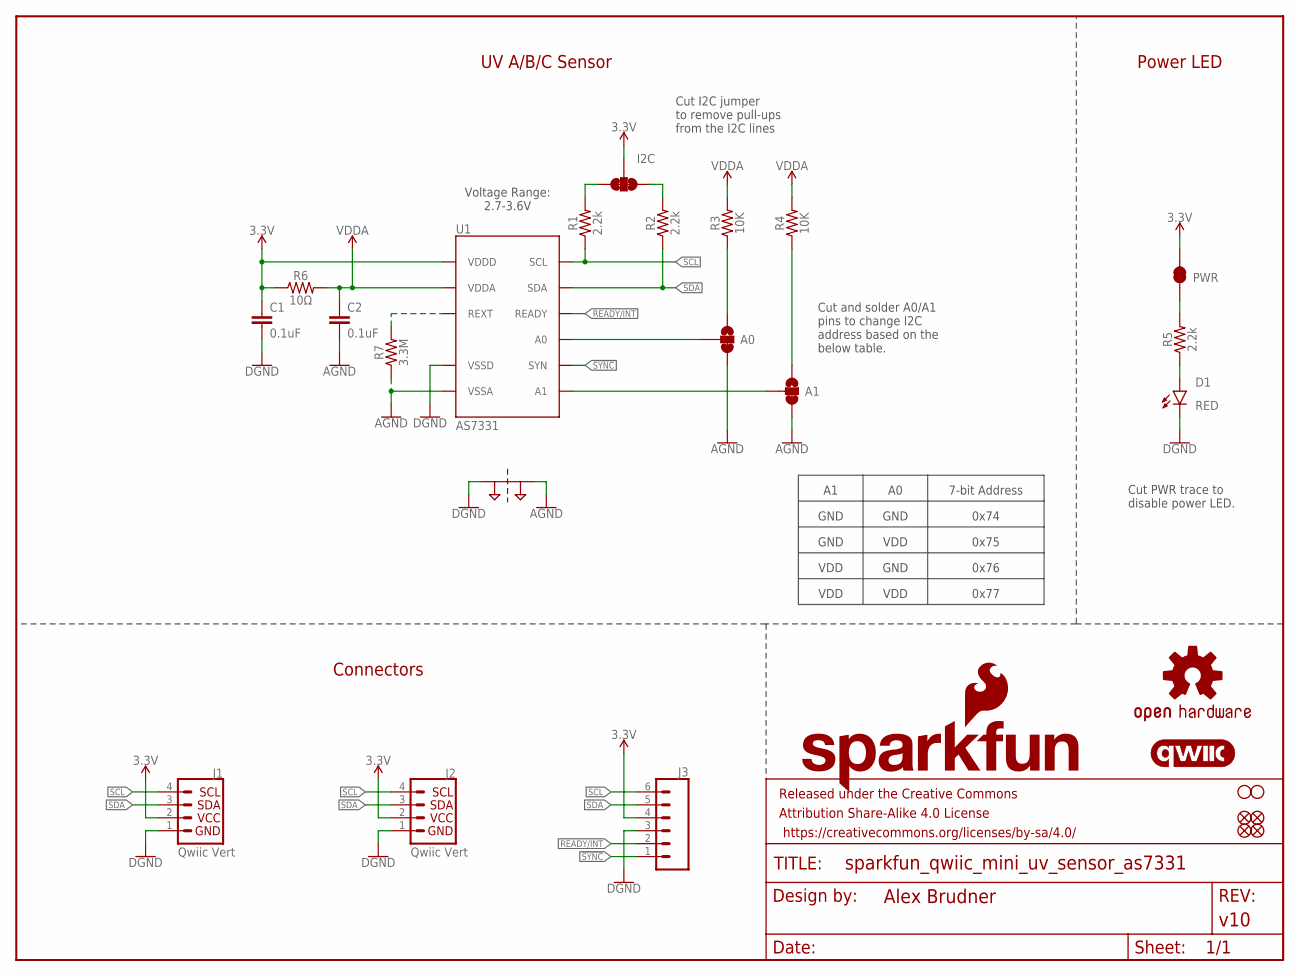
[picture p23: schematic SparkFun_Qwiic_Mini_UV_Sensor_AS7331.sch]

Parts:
A0, A1: JUMPER-SMT_3_1-NC_TRACE_SILK; SMT-JUMPER_3_1-NC_TRACE_SILK
C1, C2: 0.1uF; 0402-TIGHT
D1: RED; LED-0402
FD1, FD2, FD3, FD4: FIDUCIALUFIDUCIAL; FIDUCIAL-MICRO
FRAME1: FRAME-LETTER; CREATIVE_COMMONS
H1, H2: STAND-OFFTIGHT; STAND-OFF-TIGHT
I2C: JUMPER-SMT_3_2-NC_TRACE_SILK; SMT-JUMPER_3_2-NC_TRACE_SILK
J1, J2: Qwiic Vert; JST04_1MM_VERT
J3: CONN_06NO_SILK_NO_POP; 1X06_NO_SILK
LOGO1: SFE_LOGO_NAME.1_INCH; SFE_LOGO_NAME_.1
LOGO2: QWIIC_LOGO_CONNECTOR; QWIIC_5.5MM
LOGO3: OSHW-LOGOMINI; OSHW-LOGO-MINI
LOGO4: SFE_LOGO_FLAME.1_INCH; SFE_LOGO_FLAME_.1
PWR: JUMPER-SMT_2_NC_TRACE_SILK; SMT-JUMPER_2_NC_TRACE_SILK
R1, R2, R5: 2.2k; 0402-TIGHT
R3, R4: 10K; 0402-TIGHT
R6: 10Ω; 0402-TIGHT
R7: 3.3M; 1206
SUPPLYTIE1: 2PT_GND_TIE
U1: AS7331; OLGA16

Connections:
3.3V: C1.1, I2C.2, J1.2, J2.2, J3.4, PWR.2, R6.1, U1.10 (VDDD)
!SYNC: J3.1, U1.8 (SYN)
A0: A0.2, U1.14 (A0)
A1: A1.2, U1.7 (A1)
AGND: A0.3, A1.3, C2.2, R7.1, SUPPLYTIE1.P$2, U1.1 (VSSA), U1.2 (VSSA), U1.5 (VSSA), U1.6 (VSSA), U1.15 (VSSA), U1.16 (VSSA)
GND: C1.2, D1.C, J1.1, J2.1, J3.3, SUPPLYTIE1.P$1, U1.11 (VSSD)
unnamed: A0.1, R3.1
unnamed: A1.1, R4.1
unnamed: I2C.3, R1.2
unnamed: I2C.1, R2.2
unnamed: PWR.1, R5.2
unnamed: R7.2, U1.4 (REXT)
unnamed: D1.A, R5.1
READY/INT: J3.2, U1.9 (READY)
SCL: J1.4, J2.4, J3.6, R1.1, U1.13 (SCL)
SDA: J1.3, J2.3, J3.5, R2.1, U1.12 (SDA)
VDDA: C2.1, R3.2, R4.2, R6.2, U1.3 (VDDA)

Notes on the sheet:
Cut PWR trace to disable power LED.
Cut and solder A0/A1 pins to change I2C address based on the below table.
7-bit Address
GND
VDD
0x74
0x75
0x76
0x77
Connectors
UV A/B/C Sensor
Power LED
Cut I2C jumper to remove pull-ups from the I2C lines
Voltage Range: 2.7-3.6V

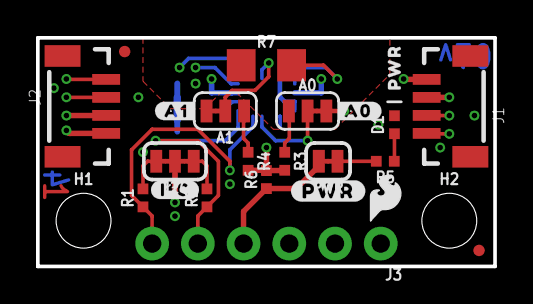
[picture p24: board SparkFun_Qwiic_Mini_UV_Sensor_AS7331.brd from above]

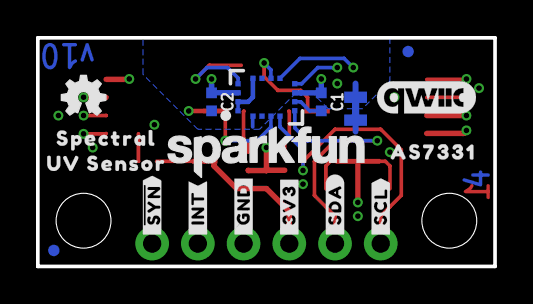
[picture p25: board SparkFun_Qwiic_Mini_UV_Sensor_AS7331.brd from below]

Board: 4 copper layers, 25.4 x 12.7 mm, 45 parts (18 on the bottom side), 17 nets.

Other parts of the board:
U$6: #I�C#0
U$7: #A0#0
U$8: #A1#0
U$9: #PWR#0
U$10: PWR0
U$11: #_SCL#0
U$12: #_SDA#0
U$13: #_3V3#0
U$14: #_GND#0
U$15: #_INT#0
U$17: UV_SENSOR0
U$18: AS73310
U$19: ORDERING_INSTRUCTIONS
U$20: SPECTRAL0
U$21: #_#SYN##0

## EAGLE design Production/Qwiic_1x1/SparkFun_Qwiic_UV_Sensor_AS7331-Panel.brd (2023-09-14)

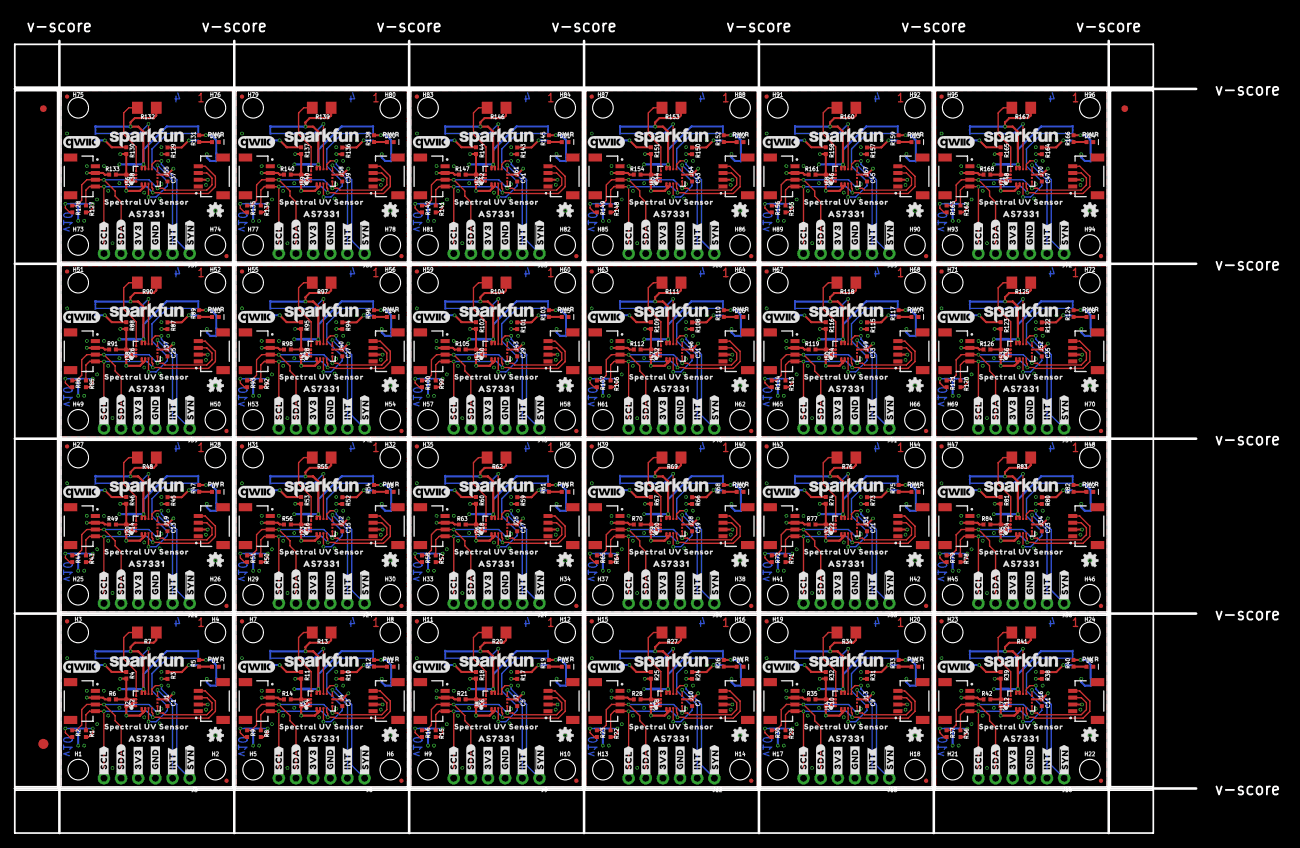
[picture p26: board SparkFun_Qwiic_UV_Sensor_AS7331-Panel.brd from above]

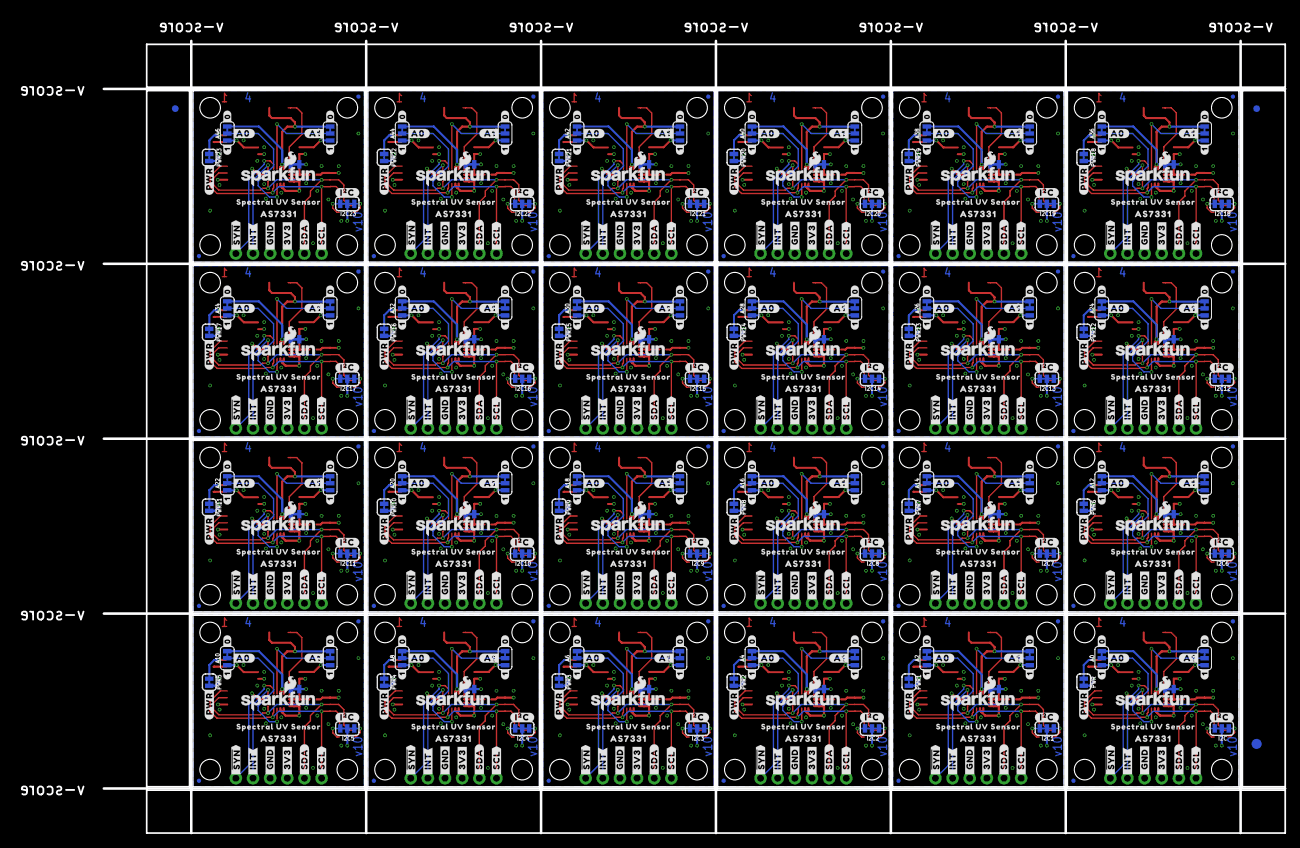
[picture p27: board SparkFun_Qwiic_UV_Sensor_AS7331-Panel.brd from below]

Board: 4 copper layers, 175.0 x 117.3 mm, 1374 parts (579 on the bottom side), 408 nets.

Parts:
A0, A1, A2, A3, A4, A5, A6, A7, A8, A9, A10, A11, A12, A13, A14, A15, A16, A17, A18, A19, A20, A21, A22, A23, A24, A25, A26, A27, A28, A29, A30, A31, A32, A33, A34, A35, A36, A37, A38, A39, A40, A41, A42, A43, A44, A45, A46, A47: JUMPER-SMT_3_1-NC_TRACE_SILK; SMT-JUMPER_3_1-NC_TRACE_SILK
C1, C2, C3, C4, C5, C6, C7, C8, C9, C10, C11, C12, C13, C14, C15, C16, C17, C18, C19, C20, C21, C22, C23, C24, C25, C26, C27, C28, C29, C30, C31, C32, C33, C34, C35, C36, C37, C38, C39, C40, C41, C42, C43, C44, C45, C46, C47, C48: 0.1uF; 0402-TIGHT
D1, D2, D3, D4, D5, D6, D7, D8, D9, D10, D11, D12, D13, D14, D15, D16, D17, D18, D19, D20, D21, D22, D23, D24: RED; LED-0402
E$1, E$2, E$3, E$4: FIDUCIAL-1X2
E$5, E$6: FIDUCIAL-1.5X3
FD1, FD2, FD3, FD4, FD5, FD6, FD7, FD8, FD9, FD10, FD11, FD12, FD13, FD14, FD15, FD16, FD17, FD18, FD19, FD20, FD21, FD22, FD23, FD24, FD25, FD26, FD27, FD28, FD29, FD30, FD31, FD32, FD33, FD34, FD35, FD36, FD37, FD38, FD39, FD40, FD41, FD42, FD43, FD44, FD45, FD46, FD47, FD48, FD49, FD50, FD51, FD52, FD53, FD54, FD55, FD56, FD57, FD58, FD59, FD60, FD61, FD62, FD63, FD64, FD65, FD66, FD67, FD68, FD69, FD70, FD71, FD72, FD73, FD74, FD75, FD76, FD77, FD78, FD79, FD80, FD81, FD82, FD83, FD84, FD85, FD86, FD87, FD88, FD89, FD90, FD91, FD92, FD93, FD94, FD95, FD96: FIDUCIALUFIDUCIAL; FIDUCIAL-MICRO
H1, H2, H3, H4, H5, H6, H7, H8, H9, H10, H11, H12, H13, H14, H15, H16, H17, H18, H19, H20, H21, H22, H23, H24, H25, H26, H27, H28, H29, H30, H31, H32, H33, H34, H35, H36, H37, H38, H39, H40, H41, H42, H43, H44, H45, H46, H47, H48, H49, H50, H51, H52, H53, H54, H55, H56, H57, H58, H59, H60, H61, H62, H63, H64, H65, H66, H67, H68, H69, H70, H71, H72, H73, H74, H75, H76, H77, H78, H79, H80, H81, H82, H83, H84, H85, H86, H87, H88, H89, H90, H91, H92, H93, H94, H95, H96: STAND-OFFTIGHT; STAND-OFF-TIGHT
I2C, I2C1, I2C2, I2C3, I2C4, I2C5, I2C6, I2C7, I2C8, I2C9, I2C10, I2C11, I2C12, I2C13, I2C14, I2C15, I2C16, I2C17, I2C18, I2C19, I2C20, I2C21, I2C22, I2C23: JUMPER-SMT_3_2-NC_TRACE_SILK; SMT-JUMPER_3_2-NC_TRACE_SILK
J1, J2, J4, J5, J7, J8, J10, J11, J13, J14, J16, J17, J19, J20, J22, J23, J25, J26, J28, J29, J31, J32, J34, J35, J37, J38, J40, J41, J43, J44, J46, J47, J49, J50, J52, J53, J55, J56, J58, J59, J61, J62, J64, J65, J67, J68, J70, J71: QWIIC_RA; JST04_1MM_RA
J3, J6, J9, J12, J15, J18, J21, J24, J27, J30, J33, J36, J39, J42, J45, J48, J51, J54, J57, J60, J63, J66, J69, J72: 1X06_NO_SILK
LOGO1, LOGO4, LOGO7, LOGO10, LOGO13, LOGO16, LOGO19, LOGO22, LOGO25, LOGO28, LOGO31, LOGO34, LOGO37, LOGO40, LOGO43, LOGO46, LOGO49, LOGO52, LOGO55, LOGO58, LOGO61, LOGO64, LOGO67, LOGO70: SFE_LOGO_NAME_FLAME.1_INCH; SFE_LOGO_NAME_FLAME_.1
LOGO2, LOGO5, LOGO8, LOGO11, LOGO14, LOGO17, LOGO20, LOGO23, LOGO26, LOGO29, LOGO32, LOGO35, LOGO38, LOGO41, LOGO44, LOGO47, LOGO50, LOGO53, LOGO56, LOGO59, LOGO62, LOGO65, LOGO68, LOGO71: QWIIC_LOGO_CONNECTOR; QWIIC_5.5MM
LOGO3, LOGO6, LOGO9, LOGO12, LOGO15, LOGO18, LOGO21, LOGO24, LOGO27, LOGO30, LOGO33, LOGO36, LOGO39, LOGO42, LOGO45, LOGO48, LOGO51, LOGO54, LOGO57, LOGO60, LOGO63, LOGO66, LOGO69, LOGO72: OSHW-LOGOMINI; OSHW-LOGO-MINI
PWR, PWR1, PWR2, PWR3, PWR4, PWR5, PWR6, PWR7, PWR8, PWR9, PWR10, PWR11, PWR12, PWR13, PWR14, PWR15, PWR16, PWR17, PWR18, PWR19, PWR20, PWR21, PWR22, PWR23: JUMPER-SMT_2_NC_TRACE_SILK; SMT-JUMPER_2_NC_TRACE_SILK
R1, R2, R5, R8, R9, R12, R15, R16, R19, R22, R23, R26, R29, R30, R33, R36, R37, R40, R43, R44, R47, R50, R51, R54, R57, R58, R61, R64, R65, R68, R71, R72, R75, R78, R79, R82, R85, R86, R89, R92, R93, R96, R99, R100, R103, R106, R107, R110, R113, R114, R117, R120, R121, R124, R127, R128, R131, R134, R135, R138, R141, R142, R145, R148, R149, R152, R155, R156, R159, R162, R163, R166: 2.2k; 0402-TIGHT
R3, R4, R10, R11, R17, R18, R24, R25, R31, R32, R38, R39, R45, R46, R52, R53, R59, R60, R66, R67, R73, R74, R80, R81, R87, R88, R94, R95, R101, R102, R108, R109, R115, R116, R122, R123, R129, R130, R136, R137, R143, R144, R150, R151, R157, R158, R164, R165: 10K; 0402-TIGHT
R6, R14, R21, R28, R35, R42, R49, R56, R63, R70, R77, R84, R91, R98, R105, R112, R119, R126, R133, R140, R147, R154, R161, R168: 10Ω; 0402-TIGHT
R7, R13, R20, R27, R34, R41, R48, R55, R62, R69, R76, R83, R90, R97, R104, R111, R118, R125, R132, R139, R146, R153, R160, R167: 3.3M; 1206
SUPPLYTIE1, SUPPLYTIE2, SUPPLYTIE3, SUPPLYTIE4, SUPPLYTIE5, SUPPLYTIE6, SUPPLYTIE7, SUPPLYTIE8, SUPPLYTIE9, SUPPLYTIE10, SUPPLYTIE11, SUPPLYTIE12, SUPPLYTIE13, SUPPLYTIE14, SUPPLYTIE15, SUPPLYTIE16, SUPPLYTIE17, SUPPLYTIE18, SUPPLYTIE19, SUPPLYTIE20, SUPPLYTIE21, SUPPLYTIE22, SUPPLYTIE23, SUPPLYTIE24: 2PT_GND_TIE
U1, U2, U3, U4, U5, U6, U7, U8, U9, U10, U11, U12, U13, U14, U15, U16, U17, U18, U19, U20, U21, U22, U23, U24: AS7331; OLGA16
U$1, U$10, U$55, U$82, U$109, U$136, U$163, U$190, U$217, U$244, U$271, U$298, U$325, U$352, U$379, U$406, U$433, U$460, U$487, U$514, U$541, U$568, U$595, U$622: PWR0
U$2, U$11, U$17, U$34, U$56, U$61, U$83, U$88, U$110, U$115, U$137, U$142, U$164, U$169, U$191, U$196, U$218, U$223, U$245, U$250, U$272, U$277, U$299, U$304, U$326, U$331, U$353, U$358, U$380, U$385, U$407, U$412, U$434, U$439, U$461, U$466, U$488, U$493, U$515, U$520, U$542, U$547, U$569, U$574, U$596, U$601, U$623, U$628: #_SCL#0
U$3, U$12, U$18, U$35, U$57, U$62, U$84, U$89, U$111, U$116, U$138, U$143, U$165, U$170, U$192, U$197, U$219, U$224, U$246, U$251, U$273, U$278, U$300, U$305, U$327, U$332, U$354, U$359, U$381, U$386, U$408, U$413, U$435, U$440, U$462, U$467, U$489, U$494, U$516, U$521, U$543, U$548, U$570, U$575, U$597, U$602, U$624, U$629: #_SDA#0
U$4, U$13, U$19, U$36, U$58, U$63, U$85, U$90, U$112, U$117, U$139, U$144, U$166, U$171, U$193, U$198, U$220, U$225, U$247, U$252, U$274, U$279, U$301, U$306, U$328, U$333, U$355, U$360, U$382, U$387, U$409, U$414, U$436, U$441, U$463, U$468, U$490, U$495, U$517, U$522, U$544, U$549, U$571, U$576, U$598, U$603, U$625, U$630: #_3V3#0
U$5, U$14, U$20, U$37, U$59, U$64, U$86, U$91, U$113, U$118, U$140, U$145, U$167, U$172, U$194, U$199, U$221, U$226, U$248, U$253, U$275, U$280, U$302, U$307, U$329, U$334, U$356, U$361, U$383, U$388, U$410, U$415, U$437, U$442, U$464, U$469, U$491, U$496, U$518, U$523, U$545, U$550, U$572, U$577, U$599, U$604, U$626, U$631: #_GND#0
U$6, U$39, U$66, U$93, U$120, U$147, U$174, U$201, U$228, U$255, U$282, U$309, U$336, U$363, U$390, U$417, U$444, U$471, U$498, U$525, U$552, U$579, U$606, U$633: #PWR#0
U$7, U$40, U$67, U$94, U$121, U$148, U$175, U$202, U$229, U$256, U$283, U$310, U$337, U$364, U$391, U$418, U$445, U$472, U$499, U$526, U$553, U$580, U$607, U$634: SFE_LOGO_FLAME_STOP_.1
U$8, U$29, U$44, U$49, U$71, U$76, U$98, U$103, U$125, U$130, U$152, U$157, U$179, U$184, U$206, U$211, U$233, U$238, U$260, U$265, U$287, U$292, U$314, U$319, U$341, U$346, U$368, U$373, U$395, U$400, U$422, U$427, U$449, U$454, U$476, U$481, U$503, U$508, U$530, U$535, U$557, U$562, U$584, U$589, U$611, U$616, U$638, U$643: SPECTRAL_UV_SENSOR0
U$9, U$43, U$70, U$97, U$124, U$151, U$178, U$205, U$232, U$259, U$286, U$313, U$340, U$367, U$394, U$421, U$448, U$475, U$502, U$529, U$556, U$583, U$610, U$637: #A0#0
U$15, U$21, U$23, U$38, U$60, U$65, U$87, U$92, U$114, U$119, U$141, U$146, U$168, U$173, U$195, U$200, U$222, U$227, U$249, U$254, U$276, U$281, U$303, U$308, U$330, U$335, U$357, U$362, U$384, U$389, U$411, U$416, U$438, U$443, U$465, U$470, U$492, U$497, U$519, U$524, U$546, U$551, U$573, U$578, U$600, U$605, U$627, U$632: #_INT#0
U$16, U$27, U$45, U$46, U$72, U$73, U$99, U$100, U$126, U$127, U$153, U$154, U$180, U$181, U$207, U$208, U$234, U$235, U$261, U$262, U$288, U$289, U$315, U$316, U$342, U$343, U$369, U$370, U$396, U$397, U$423, U$424, U$450, U$451, U$477, U$478, U$504, U$505, U$531, U$532, U$558, U$559, U$585, U$586, U$612, U$613, U$639, U$640: #_#SYN##0
U$22, U$47, U$74, U$101, U$128, U$155, U$182, U$209, U$236, U$263, U$290, U$317, U$344, U$371, U$398, U$425, U$452, U$479, U$506, U$533, U$560, U$587, U$614, U$641: SFE_LOGO_NAME_.1
U$24, U$50, U$77, U$104, U$131, U$158, U$185, U$212, U$239, U$266, U$293, U$320, U$347, U$374, U$401, U$428, U$455, U$482, U$509, U$536, U$563, U$590, U$617, U$644: #A1#0
U$25, U$28, U$41, U$48, U$68, U$75, U$95, U$102, U$122, U$129, U$149, U$156, U$176, U$183, U$203, U$210, U$230, U$237, U$257, U$264, U$284, U$291, U$311, U$318, U$338, U$345, U$365, U$372, U$392, U$399, U$419, U$426, U$446, U$453, U$473, U$480, U$500, U$507, U$527, U$534, U$554, U$561, U$581, U$588, U$608, U$615, U$635, U$642: AS73310
U$26, U$42, U$69, U$96, U$123, U$150, U$177, U$204, U$231, U$258, U$285, U$312, U$339, U$366, U$393, U$420, U$447, U$474, U$501, U$528, U$555, U$582, U$609, U$636: #I�C#0
U$30, U$31, U$51, U$52, U$78, U$79, U$105, U$106, U$132, U$133, U$159, U$160, U$186, U$187, U$213, U$214, U$240, U$241, U$267, U$268, U$294, U$295, U$321, U$322, U$348, U$349, U$375, U$376, U$402, U$403, U$429, U$430, U$456, U$457, U$483, U$484, U$510, U$511, U$537, U$538, U$564, U$565, U$591, U$592, U$618, U$619, U$645, U$646: #0#0
U$32, U$33, U$53, U$54, U$80, U$81, U$107, U$108, U$134, U$135, U$161, U$162, U$188, U$189, U$215, U$216, U$242, U$243, U$269, U$270, U$296, U$297, U$323, U$324, U$350, U$351, U$377, U$378, U$404, U$405, U$431, U$432, U$458, U$459, U$485, U$486, U$512, U$513, U$539, U$540, U$566, U$567, U$593, U$594, U$620, U$621, U$647, U$648: #1#0

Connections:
3.3V: C1.1, I2C.2, J1.2, J2.2, J3.4, PWR.2, R6.1, U1.10
3.3V1: C3.1, I2C1.2, J4.2, J5.2, J6.4, PWR1.2, R14.1, U2.10
3.3V2: C5.1, I2C2.2, J7.2, J8.2, J9.4, PWR2.2, R21.1, U3.10
3.3V3: C7.1, I2C3.2, J10.2, J11.2, J12.4, PWR3.2, R28.1, U4.10
3.3V4: C9.1, I2C4.2, J13.2, J14.2, J15.4, PWR4.2, R35.1, U5.10
3.3V5: C11.1, I2C5.2, J16.2, J17.2, J18.4, PWR5.2, R42.1, U6.10
3.3V6: C13.1, I2C6.2, J19.2, J20.2, J21.4, PWR6.2, R49.1, U7.10
3.3V7: C15.1, I2C7.2, J22.2, J23.2, J24.4, PWR7.2, R56.1, U8.10
3.3V8: C17.1, I2C8.2, J25.2, J26.2, J27.4, PWR8.2, R63.1, U9.10
3.3V9: C19.1, I2C9.2, J28.2, J29.2, J30.4, PWR9.2, R70.1, U10.10
3.3V10: C21.1, I2C10.2, J31.2, J32.2, J33.4, PWR10.2, R77.1, U11.10
3.3V11: C23.1, I2C11.2, J34.2, J35.2, J36.4, PWR11.2, R84.1, U12.10
3.3V12: C25.1, I2C12.2, J37.2, J38.2, J39.4, PWR12.2, R91.1, U13.10
3.3V13: C27.1, I2C13.2, J40.2, J41.2, J42.4, PWR13.2, R98.1, U14.10
3.3V14: C29.1, I2C14.2, J43.2, J44.2, J45.4, PWR14.2, R105.1, U15.10
3.3V15: C31.1, I2C15.2, J46.2, J47.2, J48.4, PWR15.2, R112.1, U16.10
3.3V16: C33.1, I2C16.2, J49.2, J50.2, J51.4, PWR16.2, R119.1, U17.10
3.3V17: C35.1, I2C17.2, J52.2, J53.2, J54.4, PWR17.2, R126.1, U18.10
3.3V18: C37.1, I2C18.2, J55.2, J56.2, J57.4, PWR18.2, R133.1, U19.10
3.3V19: C39.1, I2C19.2, J58.2, J59.2, J60.4, PWR19.2, R140.1, U20.10
3.3V20: C41.1, I2C20.2, J61.2, J62.2, J63.4, PWR20.2, R147.1, U21.10
3.3V21: C43.1, I2C21.2, J64.2, J65.2, J66.4, PWR21.2, R154.1, U22.10
3.3V22: C45.1, I2C22.2, J67.2, J68.2, J69.4, PWR22.2, R161.1, U23.10
3.3V23: C47.1, I2C23.2, J70.2, J71.2, J72.4, PWR23.2, R168.1, U24.10
A0: A0.2, U1.14
A1: A1.2, U1.7
A2: A2.2, U2.14
A3: A3.2, U2.7
A4: A4.2, U3.14
A5: A5.2, U3.7
A6: A6.2, U4.14
A7: A7.2, U4.7
A8: A8.2, U5.14
A9: A9.2, U5.7
A10: A10.2, U6.14
A11: A11.2, U6.7
A12: A12.2, U7.14
A13: A13.2, U7.7
A14: A14.2, U8.14
A15: A15.2, U8.7
A16: A16.2, U9.14
A17: A17.2, U9.7
A18: A18.2, U10.14
A19: A19.2, U10.7
A20: A20.2, U11.14
A21: A21.2, U11.7
A22: A22.2, U12.14
A23: A23.2, U12.7
A24: A24.2, U13.14
A25: A25.2, U13.7
A26: A26.2, U14.14
A27: A27.2, U14.7
A28: A28.2, U15.14
A29: A29.2, U15.7
A30: A30.2, U16.14
A31: A31.2, U16.7
A32: A32.2, U17.14
A33: A33.2, U17.7
A34: A34.2, U18.14
A35: A35.2, U18.7
A36: A36.2, U19.14
A37: A37.2, U19.7
A38: A38.2, U20.14
A39: A39.2, U20.7
A40: A40.2, U21.14
A41: A41.2, U21.7
A42: A42.2, U22.14
A43: A43.2, U22.7
A44: A44.2, U23.14
A45: A45.2, U23.7
A46: A46.2, U24.14
A47: A47.2, U24.7
AGND: A0.3, A1.3, C2.2, R7.1, SUPPLYTIE1.P$2, U1.1, U1.2, U1.5, U1.6, U1.15, U1.16
AGND1: A2.3, A3.3, C4.2, R13.1, SUPPLYTIE2.P$2, U2.1, U2.2, U2.5, U2.6, U2.15, U2.16
AGND2: A4.3, A5.3, C6.2, R20.1, SUPPLYTIE3.P$2, U3.1, U3.2, U3.5, U3.6, U3.15, U3.16
AGND3: A6.3, A7.3, C8.2, R27.1, SUPPLYTIE4.P$2, U4.1, U4.2, U4.5, U4.6, U4.15, U4.16
AGND4: A8.3, A9.3, C10.2, R34.1, SUPPLYTIE5.P$2, U5.1, U5.2, U5.5, U5.6, U5.15, U5.16
AGND5: A10.3, A11.3, C12.2, R41.1, SUPPLYTIE6.P$2, U6.1, U6.2, U6.5, U6.6, U6.15, U6.16
AGND6: A12.3, A13.3, C14.2, R48.1, SUPPLYTIE7.P$2, U7.1, U7.2, U7.5, U7.6, U7.15, U7.16
AGND7: A14.3, A15.3, C16.2, R55.1, SUPPLYTIE8.P$2, U8.1, U8.2, U8.5, U8.6, U8.15, U8.16
AGND8: A16.3, A17.3, C18.2, R62.1, SUPPLYTIE9.P$2, U9.1, U9.2, U9.5, U9.6, U9.15, U9.16
AGND9: A18.3, A19.3, C20.2, R69.1, SUPPLYTIE10.P$2, U10.1, U10.2, U10.5, U10.6, U10.15, U10.16
AGND10: A20.3, A21.3, C22.2, R76.1, SUPPLYTIE11.P$2, U11.1, U11.2, U11.5, U11.6, U11.15, U11.16
AGND11: A22.3, A23.3, C24.2, R83.1, SUPPLYTIE12.P$2, U12.1, U12.2, U12.5, U12.6, U12.15, U12.16
AGND12: A24.3, A25.3, C26.2, R90.1, SUPPLYTIE13.P$2, U13.1, U13.2, U13.5, U13.6, U13.15, U13.16
AGND13: A26.3, A27.3, C28.2, R97.1, SUPPLYTIE14.P$2, U14.1, U14.2, U14.5, U14.6, U14.15, U14.16
AGND14: A28.3, A29.3, C30.2, R104.1, SUPPLYTIE15.P$2, U15.1, U15.2, U15.5, U15.6, U15.15, U15.16
AGND15: A30.3, A31.3, C32.2, R111.1, SUPPLYTIE16.P$2, U16.1, U16.2, U16.5, U16.6, U16.15, U16.16
AGND16: A32.3, A33.3, C34.2, R118.1, SUPPLYTIE17.P$2, U17.1, U17.2, U17.5, U17.6, U17.15, U17.16
AGND17: A34.3, A35.3, C36.2, R125.1, SUPPLYTIE18.P$2, U18.1, U18.2, U18.5, U18.6, U18.15, U18.16
AGND18: A36.3, A37.3, C38.2, R132.1, SUPPLYTIE19.P$2, U19.1, U19.2, U19.5, U19.6, U19.15, U19.16
AGND19: A38.3, A39.3, C40.2, R139.1, SUPPLYTIE20.P$2, U20.1, U20.2, U20.5, U20.6, U20.15, U20.16
AGND20: A40.3, A41.3, C42.2, R146.1, SUPPLYTIE21.P$2, U21.1, U21.2, U21.5, U21.6, U21.15, U21.16
AGND21: A42.3, A43.3, C44.2, R153.1, SUPPLYTIE22.P$2, U22.1, U22.2, U22.5, U22.6, U22.15, U22.16
AGND22: A44.3, A45.3, C46.2, R160.1, SUPPLYTIE23.P$2, U23.1, U23.2, U23.5, U23.6, U23.15, U23.16
AGND23: A46.3, A47.3, C48.2, R167.1, SUPPLYTIE24.P$2, U24.1, U24.2, U24.5, U24.6, U24.15, U24.16
GND: C1.2, D1.C, J1.1, J2.1, J3.3, SUPPLYTIE1.P$1, U1.11
GND1: C3.2, D2.C, J4.1, J5.1, J6.3, SUPPLYTIE2.P$1, U2.11
GND2: C5.2, D3.C, J7.1, J8.1, J9.3, SUPPLYTIE3.P$1, U3.11
GND3: C7.2, D4.C, J10.1, J11.1, J12.3, SUPPLYTIE4.P$1, U4.11
GND4: C9.2, D5.C, J13.1, J14.1, J15.3, SUPPLYTIE5.P$1, U5.11
GND5: C11.2, D6.C, J16.1, J17.1, J18.3, SUPPLYTIE6.P$1, U6.11
GND6: C13.2, D7.C, J19.1, J20.1, J21.3, SUPPLYTIE7.P$1, U7.11
GND7: C15.2, D8.C, J22.1, J23.1, J24.3, SUPPLYTIE8.P$1, U8.11
GND8: C17.2, D9.C, J25.1, J26.1, J27.3, SUPPLYTIE9.P$1, U9.11
GND9: C19.2, D10.C, J28.1, J29.1, J30.3, SUPPLYTIE10.P$1, U10.11
GND10: C21.2, D11.C, J31.1, J32.1, J33.3, SUPPLYTIE11.P$1, U11.11
GND11: C23.2, D12.C, J34.1, J35.1, J36.3, SUPPLYTIE12.P$1, U12.11
GND12: C25.2, D13.C, J37.1, J38.1, J39.3, SUPPLYTIE13.P$1, U13.11
GND13: C27.2, D14.C, J40.1, J41.1, J42.3, SUPPLYTIE14.P$1, U14.11
GND14: C29.2, D15.C, J43.1, J44.1, J45.3, SUPPLYTIE15.P$1, U15.11
GND15: C31.2, D16.C, J46.1, J47.1, J48.3, SUPPLYTIE16.P$1, U16.11
GND16: C33.2, D17.C, J49.1, J50.1, J51.3, SUPPLYTIE17.P$1, U17.11
GND17: C35.2, D18.C, J52.1, J53.1, J54.3, SUPPLYTIE18.P$1, U18.11
GND18: C37.2, D19.C, J55.1, J56.1, J57.3, SUPPLYTIE19.P$1, U19.11
GND19: C39.2, D20.C, J58.1, J59.1, J60.3, SUPPLYTIE20.P$1, U20.11
GND20: C41.2, D21.C, J61.1, J62.1, J63.3, SUPPLYTIE21.P$1, U21.11
GND21: C43.2, D22.C, J64.1, J65.1, J66.3, SUPPLYTIE22.P$1, U22.11
GND22: C45.2, D23.C, J67.1, J68.1, J69.3, SUPPLYTIE23.P$1, U23.11
GND23: C47.2, D24.C, J70.1, J71.1, J72.3, SUPPLYTIE24.P$1, U24.11
unnamed: A0.1, R3.1
unnamed: A1.1, R4.1
unnamed: I2C.3, R1.2
unnamed: I2C1.3, R8.2
unnamed: I2C.1, R2.2
unnamed: I2C1.1, R9.2
unnamed: PWR.1, R5.2
unnamed: R7.2, U1.4
unnamed: D1.A, R5.1
unnamed: A2.1, R10.1
unnamed: A3.1, R11.1
unnamed: D2.A, R12.1
unnamed: R13.2, U2.4
unnamed: PWR1.1, R12.2
unnamed: I2C2.3, R15.2
unnamed: I2C2.1, R16.2
unnamed: A4.1, R17.1
unnamed: A5.1, R18.1
unnamed: D3.A, R19.1
unnamed: R20.2, U3.4
unnamed: PWR2.1, R19.2
unnamed: I2C3.3, R22.2
unnamed: I2C3.1, R23.2
unnamed: A6.1, R24.1
unnamed: A7.1, R25.1
unnamed: D4.A, R26.1
unnamed: R27.2, U4.4
unnamed: PWR3.1, R26.2
unnamed: I2C4.3, R29.2
unnamed: I2C4.1, R30.2
unnamed: A8.1, R31.1
unnamed: A9.1, R32.1
unnamed: D5.A, R33.1
unnamed: R34.2, U5.4
unnamed: PWR4.1, R33.2
unnamed: I2C5.3, R36.2
unnamed: I2C5.1, R37.2
unnamed: A10.1, R38.1
unnamed: A11.1, R39.1
unnamed: D6.A, R40.1
unnamed: R41.2, U6.4
unnamed: PWR5.1, R40.2
unnamed: I2C6.3, R43.2
unnamed: I2C6.1, R44.2
unnamed: A12.1, R45.1
unnamed: A13.1, R46.1
unnamed: D7.A, R47.1
unnamed: R48.2, U7.4
unnamed: PWR6.1, R47.2
unnamed: I2C7.3, R50.2
unnamed: I2C7.1, R51.2
unnamed: A14.1, R52.1
unnamed: A15.1, R53.1
unnamed: D8.A, R54.1
unnamed: R55.2, U8.4
unnamed: PWR7.1, R54.2
unnamed: I2C8.3, R57.2
unnamed: I2C8.1, R58.2
unnamed: A16.1, R59.1
unnamed: A17.1, R60.1
unnamed: D9.A, R61.1
unnamed: R62.2, U9.4
unnamed: PWR8.1, R61.2
unnamed: I2C9.3, R64.2
unnamed: I2C9.1, R65.2
unnamed: A18.1, R66.1
unnamed: A19.1, R67.1
unnamed: D10.A, R68.1
unnamed: R69.2, U10.4
unnamed: PWR9.1, R68.2
unnamed: I2C10.3, R71.2
unnamed: I2C10.1, R72.2
unnamed: A20.1, R73.1
unnamed: A21.1, R74.1
unnamed: D11.A, R75.1
unnamed: R76.2, U11.4
unnamed: PWR10.1, R75.2
unnamed: I2C11.3, R78.2
unnamed: I2C11.1, R79.2
unnamed: A22.1, R80.1
unnamed: A23.1, R81.1
unnamed: D12.A, R82.1
unnamed: R83.2, U12.4
unnamed: PWR11.1, R82.2
unnamed: I2C12.3, R85.2
unnamed: I2C12.1, R86.2
unnamed: A24.1, R87.1
unnamed: A25.1, R88.1
unnamed: D13.A, R89.1
unnamed: R90.2, U13.4
unnamed: PWR12.1, R89.2
unnamed: I2C13.3, R92.2
unnamed: I2C13.1, R93.2
unnamed: A26.1, R94.1
unnamed: A27.1, R95.1
unnamed: D14.A, R96.1
unnamed: R97.2, U14.4
unnamed: PWR13.1, R96.2
unnamed: I2C14.3, R99.2
unnamed: I2C14.1, R100.2
unnamed: A28.1, R101.1
unnamed: A29.1, R102.1
unnamed: D15.A, R103.1
unnamed: R104.2, U15.4
unnamed: PWR14.1, R103.2
unnamed: I2C15.3, R106.2
unnamed: I2C15.1, R107.2
unnamed: A30.1, R108.1
unnamed: A31.1, R109.1
unnamed: D16.A, R110.1
unnamed: R111.2, U16.4
unnamed: PWR15.1, R110.2
unnamed: I2C16.3, R113.2
unnamed: I2C16.1, R114.2
unnamed: A32.1, R115.1
unnamed: A33.1, R116.1
unnamed: D17.A, R117.1
unnamed: R118.2, U17.4
unnamed: PWR16.1, R117.2
unnamed: I2C17.3, R120.2
unnamed: I2C17.1, R121.2
unnamed: A34.1, R122.1
unnamed: A35.1, R123.1
unnamed: D18.A, R124.1
unnamed: R125.2, U18.4
unnamed: PWR17.1, R124.2
unnamed: I2C18.3, R127.2
unnamed: I2C18.1, R128.2
unnamed: A36.1, R129.1
unnamed: A37.1, R130.1
unnamed: D19.A, R131.1
unnamed: R132.2, U19.4
unnamed: PWR18.1, R131.2
unnamed: I2C19.3, R134.2
unnamed: I2C19.1, R135.2
unnamed: A38.1, R136.1
unnamed: A39.1, R137.1
unnamed: D20.A, R138.1
unnamed: R139.2, U20.4
unnamed: PWR19.1, R138.2
unnamed: I2C20.3, R141.2
unnamed: I2C20.1, R142.2
unnamed: A40.1, R143.1
unnamed: A41.1, R144.1
unnamed: D21.A, R145.1
unnamed: R146.2, U21.4
unnamed: PWR20.1, R145.2
unnamed: I2C21.3, R148.2
unnamed: I2C21.1, R149.2
unnamed: A42.1, R150.1
unnamed: A43.1, R151.1
unnamed: D22.A, R152.1
unnamed: R153.2, U22.4
unnamed: PWR21.1, R152.2
unnamed: I2C22.3, R155.2
unnamed: I2C22.1, R156.2
unnamed: A44.1, R157.1
unnamed: A45.1, R158.1
unnamed: D23.A, R159.1
unnamed: R160.2, U23.4
unnamed: PWR22.1, R159.2
unnamed: I2C23.3, R162.2
unnamed: I2C23.1, R163.2
unnamed: A46.1, R164.1
unnamed: A47.1, R165.1
unnamed: D24.A, R166.1
unnamed: R167.2, U24.4
unnamed: PWR23.1, R166.2
READY/INT: J3.2, U1.9
READY/INT1: J6.2, U2.9
READY/INT2: J9.2, U3.9
READY/INT3: J12.2, U4.9
READY/INT4: J15.2, U5.9
READY/INT5: J18.2, U6.9
READY/INT6: J21.2, U7.9
READY/INT7: J24.2, U8.9
READY/INT8: J27.2, U9.9
READY/INT9: J30.2, U10.9
READY/INT10: J33.2, U11.9
READY/INT11: J36.2, U12.9
READY/INT12: J39.2, U13.9
READY/INT13: J42.2, U14.9
READY/INT14: J45.2, U15.9
READY/INT15: J48.2, U16.9
READY/INT16: J51.2, U17.9
READY/INT17: J54.2, U18.9
READY/INT18: J57.2, U19.9
READY/INT19: J60.2, U20.9
READY/INT20: J63.2, U21.9
READY/INT21: J66.2, U22.9
READY/INT22: J69.2, U23.9
READY/INT23: J72.2, U24.9
SCL: J1.4, J2.4, J3.6, R1.1, U1.13
SCL1: J4.4, J5.4, J6.6, R8.1, U2.13
SCL2: J7.4, J8.4, J9.6, R15.1, U3.13
SCL3: J10.4, J11.4, J12.6, R22.1, U4.13
SCL4: J13.4, J14.4, J15.6, R29.1, U5.13
SCL5: J16.4, J17.4, J18.6, R36.1, U6.13
SCL6: J19.4, J20.4, J21.6, R43.1, U7.13
SCL7: J22.4, J23.4, J24.6, R50.1, U8.13
SCL8: J25.4, J26.4, J27.6, R57.1, U9.13
SCL9: J28.4, J29.4, J30.6, R64.1, U10.13
SCL10: J31.4, J32.4, J33.6, R71.1, U11.13
SCL11: J34.4, J35.4, J36.6, R78.1, U12.13
SCL12: J37.4, J38.4, J39.6, R85.1, U13.13
SCL13: J40.4, J41.4, J42.6, R92.1, U14.13
SCL14: J43.4, J44.4, J45.6, R99.1, U15.13
SCL15: J46.4, J47.4, J48.6, R106.1, U16.13
SCL16: J49.4, J50.4, J51.6, R113.1, U17.13
SCL17: J52.4, J53.4, J54.6, R120.1, U18.13
SCL18: J55.4, J56.4, J57.6, R127.1, U19.13
SCL19: J58.4, J59.4, J60.6, R134.1, U20.13
SCL20: J61.4, J62.4, J63.6, R141.1, U21.13
SCL21: J64.4, J65.4, J66.6, R148.1, U22.13
SCL22: J67.4, J68.4, J69.6, R155.1, U23.13
SCL23: J70.4, J71.4, J72.6, R162.1, U24.13
SDA: J1.3, J2.3, J3.5, R2.1, U1.12
SDA1: J4.3, J5.3, J6.5, R9.1, U2.12
SDA2: J7.3, J8.3, J9.5, R16.1, U3.12
SDA3: J10.3, J11.3, J12.5, R23.1, U4.12
SDA4: J13.3, J14.3, J15.5, R30.1, U5.12
SDA5: J16.3, J17.3, J18.5, R37.1, U6.12
SDA6: J19.3, J20.3, J21.5, R44.1, U7.12
SDA7: J22.3, J23.3, J24.5, R51.1, U8.12
SDA8: J25.3, J26.3, J27.5, R58.1, U9.12
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

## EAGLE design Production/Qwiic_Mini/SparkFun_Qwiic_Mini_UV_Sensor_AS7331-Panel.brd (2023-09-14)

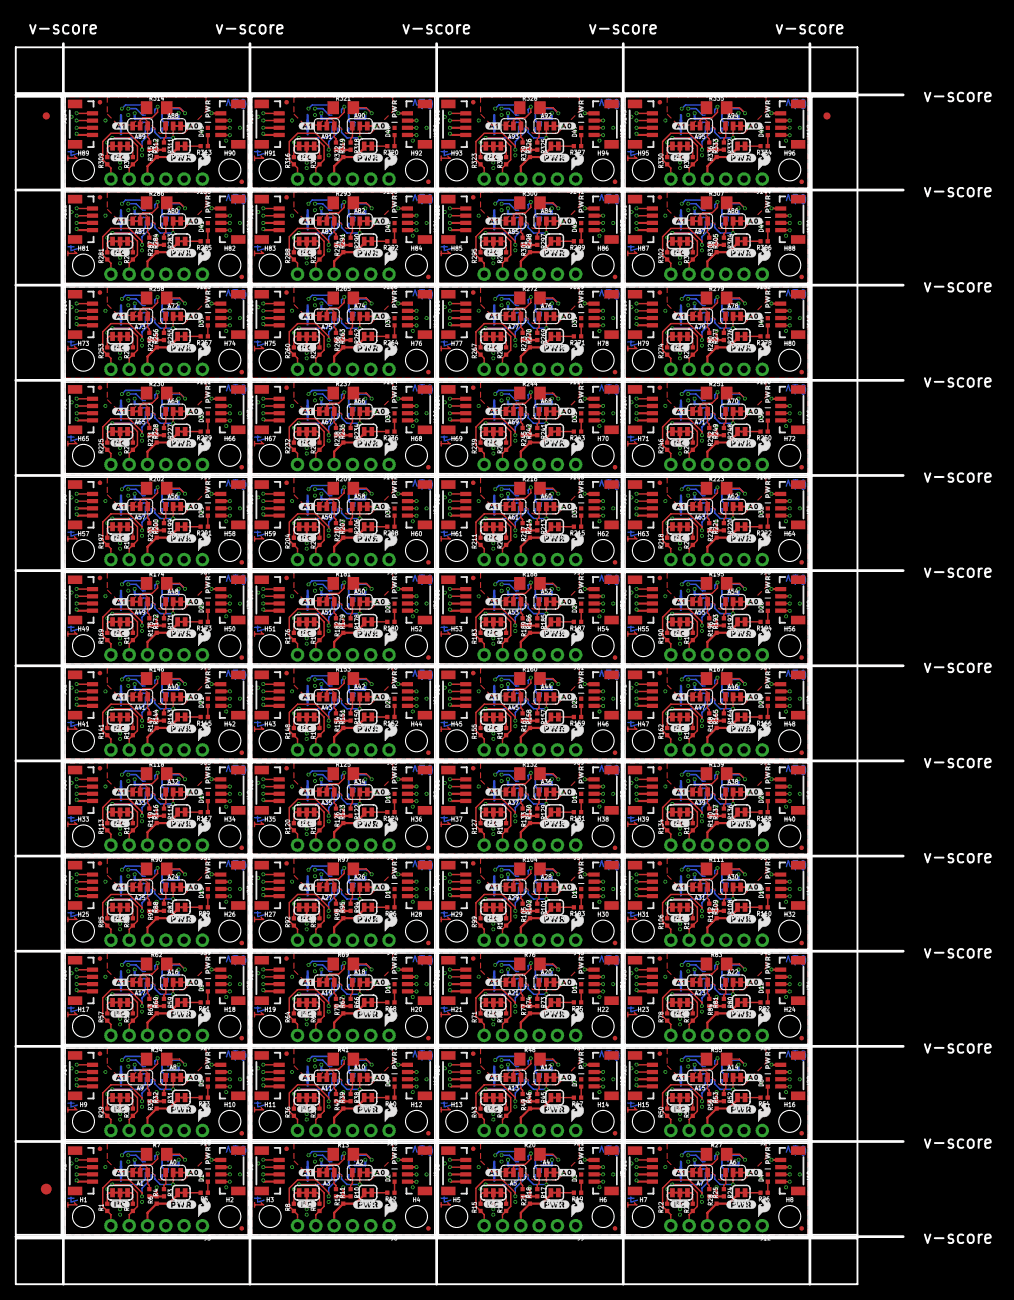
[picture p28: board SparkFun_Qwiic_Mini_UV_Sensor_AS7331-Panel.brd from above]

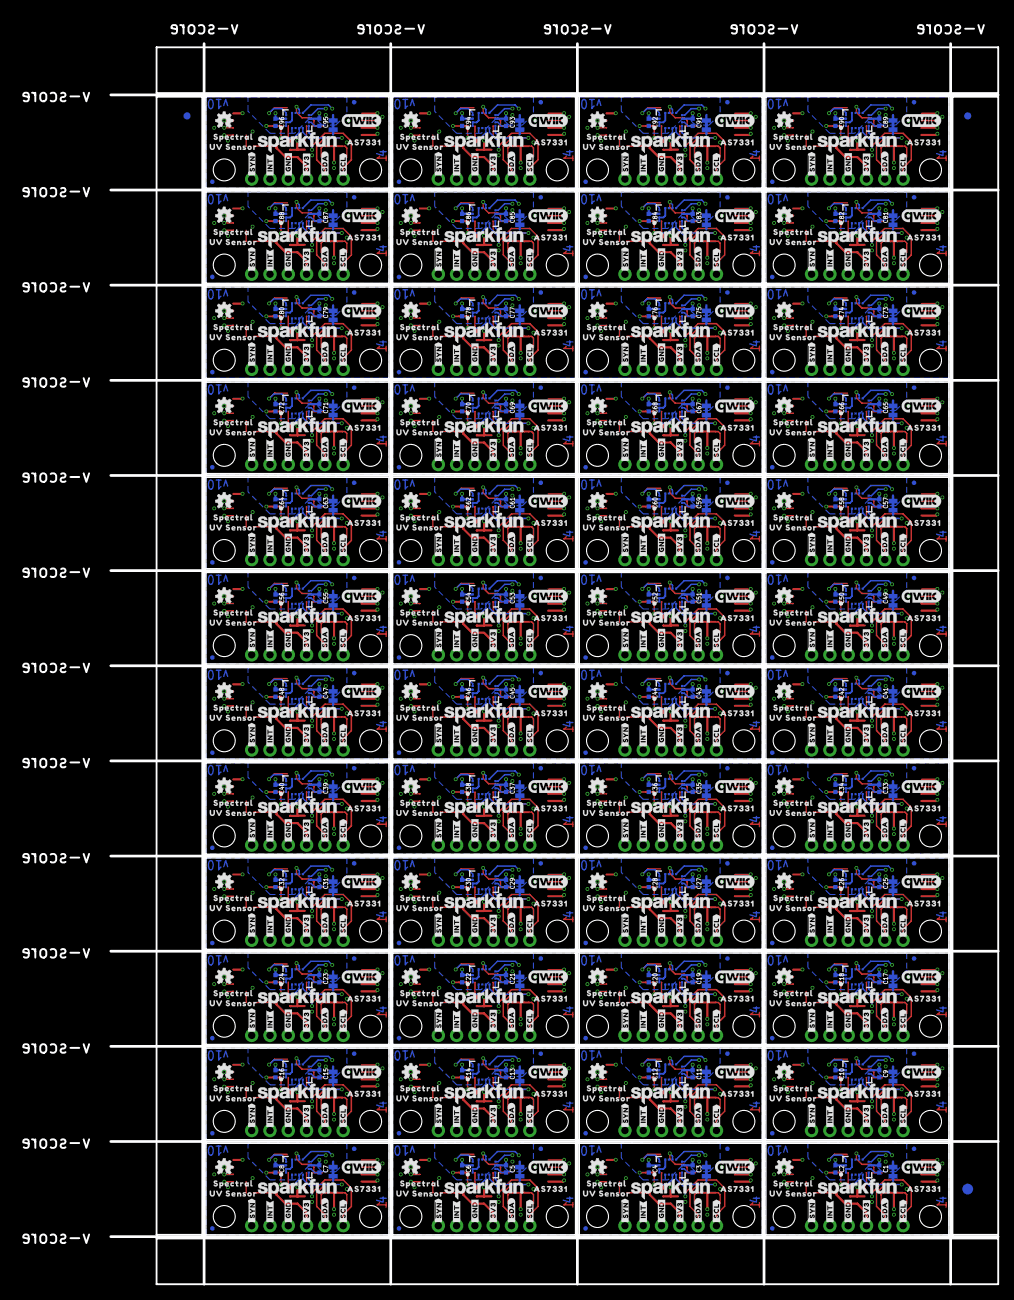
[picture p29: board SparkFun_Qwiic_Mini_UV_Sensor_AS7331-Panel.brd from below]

Board: 4 copper layers, 123.2 x 172.2 mm, 2070 parts (867 on the bottom side), 816 nets.

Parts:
A0, A1, A2, A3, A4, A5, A6, A7, A8, A9, A10, A11, A12, A13, A14, A15, A16, A17, A18, A19, A20, A21, A22, A23, A24, A25, A26, A27, A28, A29, A30, A31, A32, A33, A34, A35, A36, A37, A38, A39, A40, A41, A42, A43, A44, A45, A46, A47, A48, A49, A50, A51, A52, A53, A54, A55, A56, A57, A58, A59, A60, A61, A62, A63, A64, A65, A66, A67, A68, A69, A70, A71, A72, A73, A74, A75, A76, A77, A78, A79, A80, A81, A82, A83, A84, A85, A86, A87, A88, A89, A90, A91, A92, A93, A94, A95: JUMPER-SMT_3_1-NC_TRACE_SILK; SMT-JUMPER_3_1-NC_TRACE_SILK
C1, C2, C3, C4, C5, C6, C7, C8, C9, C10, C11, C12, C13, C14, C15, C16, C17, C18, C19, C20, C21, C22, C23, C24, C25, C26, C27, C28, C29, C30, C31, C32, C33, C34, C35, C36, C37, C38, C39, C40, C41, C42, C43, C44, C45, C46, C47, C48, C49, C50, C51, C52, C53, C54, C55, C56, C57, C58, C59, C60, C61, C62, C63, C64, C65, C66, C67, C68, C69, C70, C71, C72, C73, C74, C75, C76, C77, C78, C79, C80, C81, C82, C83, C84, C85, C86, C87, C88, C89, C90, C91, C92, C93, C94, C95, C96: 0.1uF; 0402-TIGHT
D1, D2, D3, D4, D5, D6, D7, D8, D9, D10, D11, D12, D13, D14, D15, D16, D17, D18, D19, D20, D21, D22, D23, D24, D25, D26, D27, D28, D29, D30, D31, D32, D33, D34, D35, D36, D37, D38, D39, D40, D41, D42, D43, D44, D45, D46, D47, D48: RED; LED-0402
E$1, E$2, E$3, E$4: FIDUCIAL-1X2
E$5, E$6: FIDUCIAL-1.5X3
FD1, FD2, FD3, FD4, FD5, FD6, FD7, FD8, FD9, FD10, FD11, FD12, FD13, FD14, FD15, FD16, FD17, FD18, FD19, FD20, FD21, FD22, FD23, FD24, FD25, FD26, FD27, FD28, FD29, FD30, FD31, FD32, FD33, FD34, FD35, FD36, FD37, FD38, FD39, FD40, FD41, FD42, FD43, FD44, FD45, FD46, FD47, FD48, FD49, FD50, FD51, FD52, FD53, FD54, FD55, FD56, FD57, FD58, FD59, FD60, FD61, FD62, FD63, FD64, FD65, FD66, FD67, FD68, FD69, FD70, FD71, FD72, FD73, FD74, FD75, FD76, FD77, FD78, FD79, FD80, FD81, FD82, FD83, FD84, FD85, FD86, FD87, FD88, FD89, FD90, FD91, FD92, FD93, FD94, FD95, FD96, FD97, FD98, FD99, FD100, FD101, FD102, FD103, FD104, FD105, FD106, FD107, FD108, FD109, FD110, FD111, FD112, FD113, FD114, FD115, FD116, FD117, FD118, FD119, FD120, FD121, FD122, FD123, FD124, FD125, FD126, FD127, FD128, FD129, FD130, FD131, FD132, FD133, FD134, FD135, FD136, FD137, FD138, FD139, FD140, FD141, FD142, FD143, FD144, FD145, FD146, FD147, FD148, FD149, FD150, FD151, FD152, FD153, FD154, FD155, FD156, FD157, FD158, FD159, FD160, FD161, FD162, FD163, FD164, FD165, FD166, FD167, FD168, FD169, FD170, FD171, FD172, FD173, FD174, FD175, FD176, FD177, FD178, FD179, FD180, FD181, FD182, FD183, FD184, FD185, FD186, FD187, FD188, FD189, FD190, FD191, FD192: FIDUCIALUFIDUCIAL; FIDUCIAL-MICRO
H1, H2, H3, H4, H5, H6, H7, H8, H9, H10, H11, H12, H13, H14, H15, H16, H17, H18, H19, H20, H21, H22, H23, H24, H25, H26, H27, H28, H29, H30, H31, H32, H33, H34, H35, H36, H37, H38, H39, H40, H41, H42, H43, H44, H45, H46, H47, H48, H49, H50, H51, H52, H53, H54, H55, H56, H57, H58, H59, H60, H61, H62, H63, H64, H65, H66, H67, H68, H69, H70, H71, H72, H73, H74, H75, H76, H77, H78, H79, H80, H81, H82, H83, H84, H85, H86, H87, H88, H89, H90, H91, H92, H93, H94, H95, H96: STAND-OFFTIGHT; STAND-OFF-TIGHT
I2C, I2C1, I2C2, I2C3, I2C4, I2C5, I2C6, I2C7, I2C8, I2C9, I2C10, I2C11, I2C12, I2C13, I2C14, I2C15, I2C16, I2C17, I2C18, I2C19, I2C20, I2C21, I2C22, I2C23, I2C24, I2C25, I2C26, I2C27, I2C28, I2C29, I2C30, I2C31, I2C32, I2C33, I2C34, I2C35, I2C36, I2C37, I2C38, I2C39, I2C40, I2C41, I2C42, I2C43, I2C44, I2C45, I2C46, I2C47: JUMPER-SMT_3_2-NC_TRACE_SILK; SMT-JUMPER_3_2-NC_TRACE_SILK
J1, J2, J4, J5, J7, J8, J10, J11, J13, J14, J16, J17, J19, J20, J22, J23, J25, J26, J28, J29, J31, J32, J34, J35, J37, J38, J40, J41, J43, J44, J46, J47, J49, J50, J52, J53, J55, J56, J58, J59, J61, J62, J64, J65, J67, J68, J70, J71, J73, J74, J76, J77, J79, J80, J82, J83, J85, J86, J88, J89, J91, J92, J94, J95, J97, J98, J100, J101, J103, J104, J106, J107, J109, J110, J112, J113, J115, J116, J118, J119, J121, J122, J124, J125, J127, J128, J130, J131, J133, J134, J136, J137, J139, J140, J142, J143: Qwiic Vert; JST04_1MM_VERT
J3, J6, J9, J12, J15, J18, J21, J24, J27, J30, J33, J36, J39, J42, J45, J48, J51, J54, J57, J60, J63, J66, J69, J72, J75, J78, J81, J84, J87, J90, J93, J96, J99, J102, J105, J108, J111, J114, J117, J120, J123, J126, J129, J132, J135, J138, J141, J144: 1X06_NO_SILK
LOGO1, LOGO5, LOGO9, LOGO13, LOGO17, LOGO21, LOGO25, LOGO29, LOGO33, LOGO37, LOGO41, LOGO45, LOGO49, LOGO53, LOGO57, LOGO61, LOGO65, LOGO69, LOGO73, LOGO77, LOGO81, LOGO85, LOGO89, LOGO93, LOGO97, LOGO101, LOGO105, LOGO109, LOGO113, LOGO117, LOGO121, LOGO125, LOGO129, LOGO133, LOGO137, LOGO141, LOGO145, LOGO149, LOGO153, LOGO157, LOGO161, LOGO165, LOGO169, LOGO173, LOGO177, LOGO181, LOGO185, LOGO189: SFE_LOGO_NAME.1_INCH; SFE_LOGO_NAME_.1
LOGO2, LOGO6, LOGO10, LOGO14, LOGO18, LOGO22, LOGO26, LOGO30, LOGO34, LOGO38, LOGO42, LOGO46, LOGO50, LOGO54, LOGO58, LOGO62, LOGO66, LOGO70, LOGO74, LOGO78, LOGO82, LOGO86, LOGO90, LOGO94, LOGO98, LOGO102, LOGO106, LOGO110, LOGO114, LOGO118, LOGO122, LOGO126, LOGO130, LOGO134, LOGO138, LOGO142, LOGO146, LOGO150, LOGO154, LOGO158, LOGO162, LOGO166, LOGO170, LOGO174, LOGO178, LOGO182, LOGO186, LOGO190: QWIIC_LOGO_CONNECTOR; QWIIC_5.5MM
LOGO3, LOGO7, LOGO11, LOGO15, LOGO19, LOGO23, LOGO27, LOGO31, LOGO35, LOGO39, LOGO43, LOGO47, LOGO51, LOGO55, LOGO59, LOGO63, LOGO67, LOGO71, LOGO75, LOGO79, LOGO83, LOGO87, LOGO91, LOGO95, LOGO99, LOGO103, LOGO107, LOGO111, LOGO115, LOGO119, LOGO123, LOGO127, LOGO131, LOGO135, LOGO139, LOGO143, LOGO147, LOGO151, LOGO155, LOGO159, LOGO163, LOGO167, LOGO171, LOGO175, LOGO179, LOGO183, LOGO187, LOGO191: OSHW-LOGOMINI; OSHW-LOGO-MINI
LOGO4, LOGO8, LOGO12, LOGO16, LOGO20, LOGO24, LOGO28, LOGO32, LOGO36, LOGO40, LOGO44, LOGO48, LOGO52, LOGO56, LOGO60, LOGO64, LOGO68, LOGO72, LOGO76, LOGO80, LOGO84, LOGO88, LOGO92, LOGO96, LOGO100, LOGO104, LOGO108, LOGO112, LOGO116, LOGO120, LOGO124, LOGO128, LOGO132, LOGO136, LOGO140, LOGO144, LOGO148, LOGO152, LOGO156, LOGO160, LOGO164, LOGO168, LOGO172, LOGO176, LOGO180, LOGO184, LOGO188, LOGO192: SFE_LOGO_FLAME.1_INCH; SFE_LOGO_FLAME_.1
PWR, PWR1, PWR2, PWR3, PWR4, PWR5, PWR6, PWR7, PWR8, PWR9, PWR10, PWR11, PWR12, PWR13, PWR14, PWR15, PWR16, PWR17, PWR18, PWR19, PWR20, PWR21, PWR22, PWR23, PWR24, PWR25, PWR26, PWR27, PWR28, PWR29, PWR30, PWR31, PWR32, PWR33, PWR34, PWR35, PWR36, PWR37, PWR38, PWR39, PWR40, PWR41, PWR42, PWR43, PWR44, PWR45, PWR46, PWR47: JUMPER-SMT_2_NC_TRACE_SILK; SMT-JUMPER_2_NC_TRACE_SILK
R1, R2, R5, R8, R9, R12, R15, R16, R19, R22, R23, R26, R29, R30, R33, R36, R37, R40, R43, R44, R47, R50, R51, R54, R57, R58, R61, R64, R65, R68, R71, R72, R75, R78, R79, R82, R85, R86, R89, R92, R93, R96, R99, R100, R103, R106, R107, R110, R113, R114, R117, R120, R121, R124, R127, R128, R131, R134, R135, R138, R141, R142, R145, R148, R149, R152, R155, R156, R159, R162, R163, R166, R169, R170, R173, R176, R177, R180, R183, R184, R187, R190, R191, R194, R197, R198, R201, R204, R205, R208, R211, R212, R215, R218, R219, R222, R225, R226, R229, R232, R233, R236, R239, R240, R243, R246, R247, R250, R253, R254, R257, R260, R261, R264, R267, R268, R271, R274, R275, R278, R281, R282, R285, R288, R289, R292, R295, R296, R299, R302, R303, R306, R309, R310, R313, R316, R317, R320, R323, R324, R327, R330, R331, R334: 2.2k; 0402-TIGHT
R3, R4, R10, R11, R17, R18, R24, R25, R31, R32, R38, R39, R45, R46, R52, R53, R59, R60, R66, R67, R73, R74, R80, R81, R87, R88, R94, R95, R101, R102, R108, R109, R115, R116, R122, R123, R129, R130, R136, R137, R143, R144, R150, R151, R157, R158, R164, R165, R171, R172, R178, R179, R185, R186, R192, R193, R199, R200, R206, R207, R213, R214, R220, R221, R227, R228, R234, R235, R241, R242, R248, R249, R255, R256, R262, R263, R269, R270, R276, R277, R283, R284, R290, R291, R297, R298, R304, R305, R311, R312, R318, R319, R325, R326, R332, R333: 10K; 0402-TIGHT
R6, R14, R21, R28, R35, R42, R49, R56, R63, R70, R77, R84, R91, R98, R105, R112, R119, R126, R133, R140, R147, R154, R161, R168, R175, R182, R189, R196, R203, R210, R217, R224, R231, R238, R245, R252, R259, R266, R273, R280, R287, R294, R301, R308, R315, R322, R329, R336: 10Ω; 0402-TIGHT
R7, R13, R20, R27, R34, R41, R48, R55, R62, R69, R76, R83, R90, R97, R104, R111, R118, R125, R132, R139, R146, R153, R160, R167, R174, R181, R188, R195, R202, R209, R216, R223, R230, R237, R244, R251, R258, R265, R272, R279, R286, R293, R300, R307, R314, R321, R328, R335: 3.3M; 1206
SUPPLYTIE1, SUPPLYTIE2, SUPPLYTIE3, SUPPLYTIE4, SUPPLYTIE5, SUPPLYTIE6, SUPPLYTIE7, SUPPLYTIE8, SUPPLYTIE9, SUPPLYTIE10, SUPPLYTIE11, SUPPLYTIE12, SUPPLYTIE13, SUPPLYTIE14, SUPPLYTIE15, SUPPLYTIE16, SUPPLYTIE17, SUPPLYTIE18, SUPPLYTIE19, SUPPLYTIE20, SUPPLYTIE21, SUPPLYTIE22, SUPPLYTIE23, SUPPLYTIE24, SUPPLYTIE25, SUPPLYTIE26, SUPPLYTIE27, SUPPLYTIE28, SUPPLYTIE29, SUPPLYTIE30, SUPPLYTIE31, SUPPLYTIE32, SUPPLYTIE33, SUPPLYTIE34, SUPPLYTIE35, SUPPLYTIE36, SUPPLYTIE37, SUPPLYTIE38, SUPPLYTIE39, SUPPLYTIE40, SUPPLYTIE41, SUPPLYTIE42, SUPPLYTIE43, SUPPLYTIE44, SUPPLYTIE45, SUPPLYTIE46, SUPPLYTIE47, SUPPLYTIE48: 2PT_GND_TIE
U1, U2, U3, U4, U5, U6, U7, U8, U9, U10, U11, U12, U13, U14, U15, U16, U17, U18, U19, U20, U21, U22, U23, U24, U25, U26, U27, U28, U29, U30, U31, U32, U33, U34, U35, U36, U37, U38, U39, U40, U41, U42, U43, U44, U45, U46, U47, U48: AS7331; OLGA16
U$1, U$6, U$29, U$43, U$57, U$71, U$85, U$99, U$113, U$127, U$141, U$155, U$169, U$183, U$197, U$211, U$225, U$239, U$253, U$267, U$281, U$295, U$309, U$323, U$337, U$351, U$365, U$379, U$393, U$407, U$421, U$435, U$449, U$463, U$477, U$491, U$505, U$519, U$533, U$547, U$561, U$575, U$589, U$603, U$617, U$631, U$645, U$659: #I�C#0
U$2, U$7, U$30, U$44, U$58, U$72, U$86, U$100, U$114, U$128, U$142, U$156, U$170, U$184, U$198, U$212, U$226, U$240, U$254, U$268, U$282, U$296, U$310, U$324, U$338, U$352, U$366, U$380, U$394, U$408, U$422, U$436, U$450, U$464, U$478, U$492, U$506, U$520, U$534, U$548, U$562, U$576, U$590, U$604, U$618, U$632, U$646, U$660: #A0#0
U$3, U$8, U$31, U$45, U$59, U$73, U$87, U$101, U$115, U$129, U$143, U$157, U$171, U$185, U$199, U$213, U$227, U$241, U$255, U$269, U$283, U$297, U$311, U$325, U$339, U$353, U$367, U$381, U$395, U$409, U$423, U$437, U$451, U$465, U$479, U$493, U$507, U$521, U$535, U$549, U$563, U$577, U$591, U$605, U$619, U$633, U$647, U$661: #A1#0
U$4, U$10, U$32, U$46, U$60, U$74, U$88, U$102, U$116, U$130, U$144, U$158, U$172, U$186, U$200, U$214, U$228, U$242, U$256, U$270, U$284, U$298, U$312, U$326, U$340, U$354, U$368, U$382, U$396, U$410, U$424, U$438, U$452, U$466, U$480, U$494, U$508, U$522, U$536, U$550, U$564, U$578, U$592, U$606, U$620, U$634, U$648, U$662: PWR0
U$5, U$11, U$33, U$47, U$61, U$75, U$89, U$103, U$117, U$131, U$145, U$159, U$173, U$187, U$201, U$215, U$229, U$243, U$257, U$271, U$285, U$299, U$313, U$327, U$341, U$355, U$369, U$383, U$397, U$411, U$425, U$439, U$453, U$467, U$481, U$495, U$509, U$523, U$537, U$551, U$565, U$579, U$593, U$607, U$621, U$635, U$649, U$663: #_SCL#0
U$9, U$24, U$38, U$52, U$66, U$80, U$94, U$108, U$122, U$136, U$150, U$164, U$178, U$192, U$206, U$220, U$234, U$248, U$262, U$276, U$290, U$304, U$318, U$332, U$346, U$360, U$374, U$388, U$402, U$416, U$430, U$444, U$458, U$472, U$486, U$500, U$514, U$528, U$542, U$556, U$570, U$584, U$598, U$612, U$626, U$640, U$654, U$668: #PWR#0
U$12, U$16, U$34, U$48, U$62, U$76, U$90, U$104, U$118, U$132, U$146, U$160, U$174, U$188, U$202, U$216, U$230, U$244, U$258, U$272, U$286, U$300, U$314, U$328, U$342, U$356, U$370, U$384, U$398, U$412, U$426, U$440, U$454, U$468, U$482, U$496, U$510, U$524, U$538, U$552, U$566, U$580, U$594, U$608, U$622, U$636, U$650, U$664: #_SDA#0
U$13, U$19, U$35, U$49, U$63, U$77, U$91, U$105, U$119, U$133, U$147, U$161, U$175, U$189, U$203, U$217, U$231, U$245, U$259, U$273, U$287, U$301, U$315, U$329, U$343, U$357, U$371, U$385, U$399, U$413, U$427, U$441, U$455, U$469, U$483, U$497, U$511, U$525, U$539, U$553, U$567, U$581, U$595, U$609, U$623, U$637, U$651, U$665: #_3V3#0
U$14, U$22, U$36, U$50, U$64, U$78, U$92, U$106, U$120, U$134, U$148, U$162, U$176, U$190, U$204, U$218, U$232, U$246, U$260, U$274, U$288, U$302, U$316, U$330, U$344, U$358, U$372, U$386, U$400, U$414, U$428, U$442, U$456, U$470, U$484, U$498, U$512, U$526, U$540, U$554, U$568, U$582, U$596, U$610, U$624, U$638, U$652, U$666: #_GND#0
U$15, U$23, U$37, U$51, U$65, U$79, U$93, U$107, U$121, U$135, U$149, U$163, U$177, U$191, U$205, U$219, U$233, U$247, U$261, U$275, U$289, U$303, U$317, U$331, U$345, U$359, U$373, U$387, U$401, U$415, U$429, U$443, U$457, U$471, U$485, U$499, U$513, U$527, U$541, U$555, U$569, U$583, U$597, U$611, U$625, U$639, U$653, U$667: #_INT#0
U$17, U$25, U$39, U$53, U$67, U$81, U$95, U$109, U$123, U$137, U$151, U$165, U$179, U$193, U$207, U$221, U$235, U$249, U$263, U$277, U$291, U$305, U$319, U$333, U$347, U$361, U$375, U$389, U$403, U$417, U$431, U$445, U$459, U$473, U$487, U$501, U$515, U$529, U$543, U$557, U$571, U$585, U$599, U$613, U$627, U$641, U$655, U$669: UV_SENSOR0
U$18, U$26, U$40, U$54, U$68, U$82, U$96, U$110, U$124, U$138, U$152, U$166, U$180, U$194, U$208, U$222, U$236, U$250, U$264, U$278, U$292, U$306, U$320, U$334, U$348, U$362, U$376, U$390, U$404, U$418, U$432, U$446, U$460, U$474, U$488, U$502, U$516, U$530, U$544, U$558, U$572, U$586, U$600, U$614, U$628, U$642, U$656, U$670: AS73310
U$20, U$27, U$41, U$55, U$69, U$83, U$97, U$111, U$125, U$139, U$153, U$167, U$181, U$195, U$209, U$223, U$237, U$251, U$265, U$279, U$293, U$307, U$321, U$335, U$349, U$363, U$377, U$391, U$405, U$419, U$433, U$447, U$461, U$475, U$489, U$503, U$517, U$531, U$545, U$559, U$573, U$587, U$601, U$615, U$629, U$643, U$657, U$671: SPECTRAL0
U$21, U$28, U$42, U$56, U$70, U$84, U$98, U$112, U$126, U$140, U$154, U$168, U$182, U$196, U$210, U$224, U$238, U$252, U$266, U$280, U$294, U$308, U$322, U$336, U$350, U$364, U$378, U$392, U$406, U$420, U$434, U$448, U$462, U$476, U$490, U$504, U$518, U$532, U$546, U$560, U$574, U$588, U$602, U$616, U$630, U$644, U$658, U$672: #_#SYN##0

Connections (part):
3.3V: C1.1, I2C.2, J1.2, J2.2, J3.4, PWR.2, R6.1, U1.10
3.3V1: C3.1, I2C1.2, J4.2, J5.2, J6.4, PWR1.2, R14.1, U2.10
3.3V2: C5.1, I2C2.2, J7.2, J8.2, J9.4, PWR2.2, R21.1, U3.10
3.3V3: C7.1, I2C3.2, J10.2, J11.2, J12.4, PWR3.2, R28.1, U4.10
3.3V4: C9.1, I2C4.2, J13.2, J14.2, J15.4, PWR4.2, R35.1, U5.10
3.3V5: C11.1, I2C5.2, J16.2, J17.2, J18.4, PWR5.2, R42.1, U6.10
3.3V6: C13.1, I2C6.2, J19.2, J20.2, J21.4, PWR6.2, R49.1, U7.10
3.3V7: C15.1, I2C7.2, J22.2, J23.2, J24.4, PWR7.2, R56.1, U8.10
3.3V8: C17.1, I2C8.2, J25.2, J26.2, J27.4, PWR8.2, R63.1, U9.10
3.3V9: C19.1, I2C9.2, J28.2, J29.2, J30.4, PWR9.2, R70.1, U10.10
3.3V10: C21.1, I2C10.2, J31.2, J32.2, J33.4, PWR10.2, R77.1, U11.10
3.3V11: C23.1, I2C11.2, J34.2, J35.2, J36.4, PWR11.2, R84.1, U12.10
3.3V12: C25.1, I2C12.2, J37.2, J38.2, J39.4, PWR12.2, R91.1, U13.10
3.3V13: C27.1, I2C13.2, J40.2, J41.2, J42.4, PWR13.2, R98.1, U14.10
3.3V14: C29.1, I2C14.2, J43.2, J44.2, J45.4, PWR14.2, R105.1, U15.10
3.3V15: C31.1, I2C15.2, J46.2, J47.2, J48.4, PWR15.2, R112.1, U16.10
3.3V16: C33.1, I2C16.2, J49.2, J50.2, J51.4, PWR16.2, R119.1, U17.10
3.3V17: C35.1, I2C17.2, J52.2, J53.2, J54.4, PWR17.2, R126.1, U18.10
3.3V18: C37.1, I2C18.2, J55.2, J56.2, J57.4, PWR18.2, R133.1, U19.10
3.3V19: C39.1, I2C19.2, J58.2, J59.2, J60.4, PWR19.2, R140.1, U20.10
3.3V20: C41.1, I2C20.2, J61.2, J62.2, J63.4, PWR20.2, R147.1, U21.10
3.3V21: C43.1, I2C21.2, J64.2, J65.2, J66.4, PWR21.2, R154.1, U22.10
3.3V22: C45.1, I2C22.2, J67.2, J68.2, J69.4, PWR22.2, R161.1, U23.10
3.3V23: C47.1, I2C23.2, J70.2, J71.2, J72.4, PWR23.2, R168.1, U24.10
3.3V24: C49.1, I2C24.2, J73.2, J74.2, J75.4, PWR24.2, R175.1, U25.10
3.3V25: C51.1, I2C25.2, J76.2, J77.2, J78.4, PWR25.2, R182.1, U26.10
3.3V26: C53.1, I2C26.2, J79.2, J80.2, J81.4, PWR26.2, R189.1, U27.10
3.3V27: C55.1, I2C27.2, J82.2, J83.2, J84.4, PWR27.2, R196.1, U28.10
3.3V28: C57.1, I2C28.2, J85.2, J86.2, J87.4, PWR28.2, R203.1, U29.10
3.3V29: C59.1, I2C29.2, J88.2, J89.2, J90.4, PWR29.2, R210.1, U30.10
3.3V30: C61.1, I2C30.2, J91.2, J92.2, J93.4, PWR30.2, R217.1, U31.10
3.3V31: C63.1, I2C31.2, J94.2, J95.2, J96.4, PWR31.2, R224.1, U32.10
3.3V32: C65.1, I2C32.2, J97.2, J98.2, J99.4, PWR32.2, R231.1, U33.10
3.3V33: C67.1, I2C33.2, J100.2, J101.2, J102.4, PWR33.2, R238.1, U34.10
3.3V34: C69.1, I2C34.2, J103.2, J104.2, J105.4, PWR34.2, R245.1, U35.10
3.3V35: C71.1, I2C35.2, J106.2, J107.2, J108.4, PWR35.2, R252.1, U36.10
3.3V36: C73.1, I2C36.2, J109.2, J110.2, J111.4, PWR36.2, R259.1, U37.10
3.3V37: C75.1, I2C37.2, J112.2, J113.2, J114.4, PWR37.2, R266.1, U38.10
3.3V38: C77.1, I2C38.2, J115.2, J116.2, J117.4, PWR38.2, R273.1, U39.10
3.3V39: C79.1, I2C39.2, J118.2, J119.2, J120.4, PWR39.2, R280.1, U40.10
3.3V40: C81.1, I2C40.2, J121.2, J122.2, J123.4, PWR40.2, R287.1, U41.10
3.3V41: C83.1, I2C41.2, J124.2, J125.2, J126.4, PWR41.2, R294.1, U42.10
3.3V42: C85.1, I2C42.2, J127.2, J128.2, J129.4, PWR42.2, R301.1, U43.10
3.3V43: C87.1, I2C43.2, J130.2, J131.2, J132.4, PWR43.2, R308.1, U44.10
3.3V44: C89.1, I2C44.2, J133.2, J134.2, J135.4, PWR44.2, R315.1, U45.10
3.3V45: C91.1, I2C45.2, J136.2, J137.2, J138.4, PWR45.2, R322.1, U46.10
3.3V46: C93.1, I2C46.2, J139.2, J140.2, J141.4, PWR46.2, R329.1, U47.10
3.3V47: C95.1, I2C47.2, J142.2, J143.2, J144.4, PWR47.2, R336.1, U48.10
!SYNC: J3.1, U1.8
!SYNC1: J6.1, U2.8
!SYNC2: J9.1, U3.8
!SYNC3: J12.1, U4.8
!SYNC4: J15.1, U5.8
!SYNC5: J18.1, U6.8
!SYNC6: J21.1, U7.8
!SYNC7: J24.1, U8.8
!SYNC8: J27.1, U9.8
!SYNC9: J30.1, U10.8
!SYNC10: J33.1, U11.8
!SYNC11: J36.1, U12.8
!SYNC12: J39.1, U13.8
!SYNC13: J42.1, U14.8
!SYNC14: J45.1, U15.8
!SYNC15: J48.1, U16.8
!SYNC16: J51.1, U17.8
!SYNC17: J54.1, U18.8
!SYNC18: J57.1, U19.8
!SYNC19: J60.1, U20.8
!SYNC20: J63.1, U21.8
!SYNC21: J66.1, U22.8
!SYNC22: J69.1, U23.8
!SYNC23: J72.1, U24.8
!SYNC24: J75.1, U25.8
!SYNC25: J78.1, U26.8
!SYNC26: J81.1, U27.8
!SYNC27: J84.1, U28.8
!SYNC28: J87.1, U29.8
!SYNC29: J90.1, U30.8
!SYNC30: J93.1, U31.8
!SYNC31: J96.1, U32.8
!SYNC32: J99.1, U33.8
!SYNC33: J102.1, U34.8
!SYNC34: J105.1, U35.8
!SYNC35: J108.1, U36.8
!SYNC36: J111.1, U37.8
!SYNC37: J114.1, U38.8
!SYNC38: J117.1, U39.8
!SYNC39: J120.1, U40.8
!SYNC40: J123.1, U41.8
!SYNC41: J126.1, U42.8
!SYNC42: J129.1, U43.8
!SYNC43: J132.1, U44.8
!SYNC44: J135.1, U45.8
!SYNC45: J138.1, U46.8
!SYNC46: J141.1, U47.8
!SYNC47: J144.1, U48.8
A0: A0.2, U1.14
A1: A1.2, U1.7
A2: A2.2, U2.14
A3: A3.2, U2.7
A4: A4.2, U3.14
A5: A5.2, U3.7
A6: A6.2, U4.14
A7: A7.2, U4.7
A8: A8.2, U5.14
A9: A9.2, U5.7
A10: A10.2, U6.14
A11: A11.2, U6.7
A12: A12.2, U7.14
A13: A13.2, U7.7
A14: A14.2, U8.14
A15: A15.2, U8.7
A16: A16.2, U9.14
A17: A17.2, U9.7
A18: A18.2, U10.14
A19: A19.2, U10.7
A20: A20.2, U11.14
A21: A21.2, U11.7
A22: A22.2, U12.14
A23: A23.2, U12.7
A24: A24.2, U13.14
A25: A25.2, U13.7
A26: A26.2, U14.14
A27: A27.2, U14.7
A28: A28.2, U15.14
A29: A29.2, U15.7
A30: A30.2, U16.14
A31: A31.2, U16.7
A32: A32.2, U17.14
A33: A33.2, U17.7
A34: A34.2, U18.14
A35: A35.2, U18.7
A36: A36.2, U19.14
A37: A37.2, U19.7
A38: A38.2, U20.14
A39: A39.2, U20.7
A40: A40.2, U21.14
A41: A41.2, U21.7
A42: A42.2, U22.14
A43: A43.2, U22.7
A44: A44.2, U23.14
A45: A45.2, U23.7
A46: A46.2, U24.14
A47: A47.2, U24.7
A48: A48.2, U25.14
A49: A49.2, U25.7
A50: A50.2, U26.14
A51: A51.2, U26.7
A52: A52.2, U27.14
A53: A53.2, U27.7
A54: A54.2, U28.14
A55: A55.2, U28.7
A56: A56.2, U29.14
A57: A57.2, U29.7
A58: A58.2, U30.14
A59: A59.2, U30.7
A60: A60.2, U31.14
A61: A61.2, U31.7
A62: A62.2, U32.14
A63: A63.2, U32.7
A64: A64.2, U33.14
A65: A65.2, U33.7
A66: A66.2, U34.14
A67: A67.2, U34.7
A68: A68.2, U35.14
A69: A69.2, U35.7
A70: A70.2, U36.14
A71: A71.2, U36.7
A72: A72.2, U37.14
A73: A73.2, U37.7
A74: A74.2, U38.14
A75: A75.2, U38.7
A76: A76.2, U39.14
A77: A77.2, U39.7
A78: A78.2, U40.14
A79: A79.2, U40.7
A80: A80.2, U41.14
A81: A81.2, U41.7
A82: A82.2, U42.14
A83: A83.2, U42.7
A84: A84.2, U43.14
A85: A85.2, U43.7
A86: A86.2, U44.14
A87: A87.2, U44.7
A88: A88.2, U45.14
A89: A89.2, U45.7
A90: A90.2, U46.14
A91: A91.2, U46.7
A92: A92.2, U47.14
A93: A93.2, U47.7
A94: A94.2, U48.14
A95: A95.2, U48.7
AGND: A0.3, A1.3, C2.2, R7.1, SUPPLYTIE1.P$2, U1.1, U1.2, U1.5, U1.6, U1.15, U1.16
AGND1: A2.3, A3.3, C4.2, R13.1, SUPPLYTIE2.P$2, U2.1, U2.2, U2.5, U2.6, U2.15, U2.16
AGND2: A4.3, A5.3, C6.2, R20.1, SUPPLYTIE3.P$2, U3.1, U3.2, U3.5, U3.6, U3.15, U3.16
AGND3: A6.3, A7.3, C8.2, R27.1, SUPPLYTIE4.P$2, U4.1, U4.2, U4.5, U4.6, U4.15, U4.16
AGND4: A8.3, A9.3, C10.2, R34.1, SUPPLYTIE5.P$2, U5.1, U5.2, U5.5, U5.6, U5.15, U5.16
AGND5: A10.3, A11.3, C12.2, R41.1, SUPPLYTIE6.P$2, U6.1, U6.2, U6.5, U6.6, U6.15, U6.16
AGND6: A12.3, A13.3, C14.2, R48.1, SUPPLYTIE7.P$2, U7.1, U7.2, U7.5, U7.6, U7.15, U7.16
AGND7: A14.3, A15.3, C16.2, R55.1, SUPPLYTIE8.P$2, U8.1, U8.2, U8.5, U8.6, U8.15, U8.16
AGND8: A16.3, A17.3, C18.2, R62.1, SUPPLYTIE9.P$2, U9.1, U9.2, U9.5, U9.6, U9.15, U9.16
AGND9: A18.3, A19.3, C20.2, R69.1, SUPPLYTIE10.P$2, U10.1, U10.2, U10.5, U10.6, U10.15, U10.16
AGND10: A20.3, A21.3, C22.2, R76.1, SUPPLYTIE11.P$2, U11.1, U11.2, U11.5, U11.6, U11.15, U11.16
AGND11: A22.3, A23.3, C24.2, R83.1, SUPPLYTIE12.P$2, U12.1, U12.2, U12.5, U12.6, U12.15, U12.16
AGND12: A24.3, A25.3, C26.2, R90.1, SUPPLYTIE13.P$2, U13.1, U13.2, U13.5, U13.6, U13.15, U13.16
AGND13: A26.3, A27.3, C28.2, R97.1, SUPPLYTIE14.P$2, U14.1, U14.2, U14.5, U14.6, U14.15, U14.16
AGND14: A28.3, A29.3, C30.2, R104.1, SUPPLYTIE15.P$2, U15.1, U15.2, U15.5, U15.6, U15.15, U15.16
AGND15: A30.3, A31.3, C32.2, R111.1, SUPPLYTIE16.P$2, U16.1, U16.2, U16.5, U16.6, U16.15, U16.16
AGND16: A32.3, A33.3, C34.2, R118.1, SUPPLYTIE17.P$2, U17.1, U17.2, U17.5, U17.6, U17.15, U17.16
AGND17: A34.3, A35.3, C36.2, R125.1, SUPPLYTIE18.P$2, U18.1, U18.2, U18.5, U18.6, U18.15, U18.16
AGND18: A36.3, A37.3, C38.2, R132.1, SUPPLYTIE19.P$2, U19.1, U19.2, U19.5, U19.6, U19.15, U19.16
AGND19: A38.3, A39.3, C40.2, R139.1, SUPPLYTIE20.P$2, U20.1, U20.2, U20.5, U20.6, U20.15, U20.16
AGND20: A40.3, A41.3, C42.2, R146.1, SUPPLYTIE21.P$2, U21.1, U21.2, U21.5, U21.6, U21.15, U21.16
AGND21: A42.3, A43.3, C44.2, R153.1, SUPPLYTIE22.P$2, U22.1, U22.2, U22.5, U22.6, U22.15, U22.16
AGND22: A44.3, A45.3, C46.2, R160.1, SUPPLYTIE23.P$2, U23.1, U23.2, U23.5, U23.6, U23.15, U23.16
AGND23: A46.3, A47.3, C48.2, R167.1, SUPPLYTIE24.P$2, U24.1, U24.2, U24.5, U24.6, U24.15, U24.16
AGND24: A48.3, A49.3, C50.2, R174.1, SUPPLYTIE25.P$2, U25.1, U25.2, U25.5, U25.6, U25.15, U25.16
AGND25: A50.3, A51.3, C52.2, R181.1, SUPPLYTIE26.P$2, U26.1, U26.2, U26.5, U26.6, U26.15, U26.16
AGND26: A52.3, A53.3, C54.2, R188.1, SUPPLYTIE27.P$2, U27.1, U27.2, U27.5, U27.6, U27.15, U27.16
AGND27: A54.3, A55.3, C56.2, R195.1, SUPPLYTIE28.P$2, U28.1, U28.2, U28.5, U28.6, U28.15, U28.16
AGND28: A56.3, A57.3, C58.2, R202.1, SUPPLYTIE29.P$2, U29.1, U29.2, U29.5, U29.6, U29.15, U29.16
AGND29: A58.3, A59.3, C60.2, R209.1, SUPPLYTIE30.P$2, U30.1, U30.2, U30.5, U30.6, U30.15, U30.16
AGND30: A60.3, A61.3, C62.2, R216.1, SUPPLYTIE31.P$2, U31.1, U31.2, U31.5, U31.6, U31.15, U31.16
AGND31: A62.3, A63.3, C64.2, R223.1, SUPPLYTIE32.P$2, U32.1, U32.2, U32.5, U32.6, U32.15, U32.16
AGND32: A64.3, A65.3, C66.2, R230.1, SUPPLYTIE33.P$2, U33.1, U33.2, U33.5, U33.6, U33.15, U33.16
AGND33: A66.3, A67.3, C68.2, R237.1, SUPPLYTIE34.P$2, U34.1, U34.2, U34.5, U34.6, U34.15, U34.16
AGND34: A68.3, A69.3, C70.2, R244.1, SUPPLYTIE35.P$2, U35.1, U35.2, U35.5, U35.6, U35.15, U35.16
AGND35: A70.3, A71.3, C72.2, R251.1, SUPPLYTIE36.P$2, U36.1, U36.2, U36.5, U36.6, U36.15, U36.16
AGND36: A72.3, A73.3, C74.2, R258.1, SUPPLYTIE37.P$2, U37.1, U37.2, U37.5, U37.6, U37.15, U37.16
AGND37: A74.3, A75.3, C76.2, R265.1, SUPPLYTIE38.P$2, U38.1, U38.2, U38.5, U38.6, U38.15, U38.16
AGND38: A76.3, A77.3, C78.2, R272.1, SUPPLYTIE39.P$2, U39.1, U39.2, U39.5, U39.6, U39.15, U39.16
AGND39: A78.3, A79.3, C80.2, R279.1, SUPPLYTIE40.P$2, U40.1, U40.2, U40.5, U40.6, U40.15, U40.16
AGND40: A80.3, A81.3, C82.2, R286.1, SUPPLYTIE41.P$2, U41.1, U41.2, U41.5, U41.6, U41.15, U41.16
AGND41: A82.3, A83.3, C84.2, R293.1, SUPPLYTIE42.P$2, U42.1, U42.2, U42.5, U42.6, U42.15, U42.16
AGND42: A84.3, A85.3, C86.2, R300.1, SUPPLYTIE43.P$2, U43.1, U43.2, U43.5, U43.6, U43.15, U43.16
AGND43: A86.3, A87.3, C88.2, R307.1, SUPPLYTIE44.P$2, U44.1, U44.2, U44.5, U44.6, U44.15, U44.16
AGND44: A88.3, A89.3, C90.2, R314.1, SUPPLYTIE45.P$2, U45.1, U45.2, U45.5, U45.6, U45.15, U45.16
AGND45: A90.3, A91.3, C92.2, R321.1, SUPPLYTIE46.P$2, U46.1, U46.2, U46.5, U46.6, U46.15, U46.16
AGND46: A92.3, A93.3, C94.2, R328.1, SUPPLYTIE47.P$2, U47.1, U47.2, U47.5, U47.6, U47.15, U47.16
AGND47: A94.3, A95.3, C96.2, R335.1, SUPPLYTIE48.P$2, U48.1, U48.2, U48.5, U48.6, U48.15, U48.16
GND: C1.2, D1.C, J1.1, J2.1, J3.3, SUPPLYTIE1.P$1, U1.11
GND1: C3.2, D2.C, J4.1, J5.1, J6.3, SUPPLYTIE2.P$1, U2.11
GND2: C5.2, D3.C, J7.1, J8.1, J9.3, SUPPLYTIE3.P$1, U3.11
GND3: C7.2, D4.C, J10.1, J11.1, J12.3, SUPPLYTIE4.P$1, U4.11
GND4: C9.2, D5.C, J13.1, J14.1, J15.3, SUPPLYTIE5.P$1, U5.11
GND5: C11.2, D6.C, J16.1, J17.1, J18.3, SUPPLYTIE6.P$1, U6.11
GND6: C13.2, D7.C, J19.1, J20.1, J21.3, SUPPLYTIE7.P$1, U7.11
GND7: C15.2, D8.C, J22.1, J23.1, J24.3, SUPPLYTIE8.P$1, U8.11
GND8: C17.2, D9.C, J25.1, J26.1, J27.3, SUPPLYTIE9.P$1, U9.11
GND9: C19.2, D10.C, J28.1, J29.1, J30.3, SUPPLYTIE10.P$1, U10.11
GND10: C21.2, D11.C, J31.1, J32.1, J33.3, SUPPLYTIE11.P$1, U11.11
GND11: C23.2, D12.C, J34.1, J35.1, J36.3, SUPPLYTIE12.P$1, U12.11
GND12: C25.2, D13.C, J37.1, J38.1, J39.3, SUPPLYTIE13.P$1, U13.11
GND13: C27.2, D14.C, J40.1, J41.1, J42.3, SUPPLYTIE14.P$1, U14.11
GND14: C29.2, D15.C, J43.1, J44.1, J45.3, SUPPLYTIE15.P$1, U15.11
GND15: C31.2, D16.C, J46.1, J47.1, J48.3, SUPPLYTIE16.P$1, U16.11
GND16: C33.2, D17.C, J49.1, J50.1, J51.3, SUPPLYTIE17.P$1, U17.11
GND17: C35.2, D18.C, J52.1, J53.1, J54.3, SUPPLYTIE18.P$1, U18.11
GND18: C37.2, D19.C, J55.1, J56.1, J57.3, SUPPLYTIE19.P$1, U19.11
GND19: C39.2, D20.C, J58.1, J59.1, J60.3, SUPPLYTIE20.P$1, U20.11
GND20: C41.2, D21.C, J61.1, J62.1, J63.3, SUPPLYTIE21.P$1, U21.11
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

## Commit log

2023-09-11 Add v01 protos.
    [SparkFun_Qwiic_Mini_UV_Sensor_AS7331.brd, SparkFun_Qwiic_Mini_UV_Sensor_AS7331.sch, SparkFun_Qwiic_UV_Sensor_AS7331.brd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]
2023-09-12 v01 ready for review
    [SparkFun_Qwiic_Mini_UV_Sensor_AS7331.brd, SparkFun_Qwiic_Mini_UV_Sensor_AS7331.sch, SparkFun_Qwiic_UV_Sensor_AS7331.brd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]
2023-09-14 Pushing to v10
    Panelize and push to v10.
    [SparkFun_Qwiic_Mini_UV_Sensor_AS7331.brd, SparkFun_Qwiic_Mini_UV_Sensor_AS7331.sch, SparkFun_Qwiic_UV_Sensor_AS7331.brd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]
2023-09-14 Remove unneeded folders and add production files.
    [SparkFun_Qwiic_Mini_UV_Sensor_AS7331-Panel.brd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]
2023-12-07 Examples update
    Adding code snippets for examples & screenshot of serial printout.

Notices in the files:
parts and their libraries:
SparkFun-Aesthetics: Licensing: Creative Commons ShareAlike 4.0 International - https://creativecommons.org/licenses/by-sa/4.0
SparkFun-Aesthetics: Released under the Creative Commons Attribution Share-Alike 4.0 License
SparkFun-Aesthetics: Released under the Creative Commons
